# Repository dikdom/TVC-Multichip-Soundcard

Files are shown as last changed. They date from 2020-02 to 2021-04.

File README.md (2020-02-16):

# TVC-Multichip-Soundcard
## English description
  
This is soundcard developed specifically for the Videoton TV Computer. You can find sources of the firmware and music player in the 
**source/** directory and you can also find the plans of the PCB (with schematic) and gerber files in case you would like to do one in 
the **hardware/** directory.

The card is capable of handling three different kind of sound chips: SN76489, SAA1099 and YM3812

These chips' specifications can be found in the **doc/** directory. There is a small overview about the card (Hungarian) if you would like 
to code it.

## Magyar leírás

Ez a hangkártya a Videoton TV Computer számítógéphez készült. Minden megtalálható hozzá: a firmware és a zenelejátszó források a **source/** 
könyvtár alatt, a kapcsolási rajz és nyákterv (gerber file-ok) pedig a **hardware/** könyvtárban van.

A kártya a következő típusú chipeket tudja fogadni (akár egyszerre): SN76489, SAA1099 and YM3812

Van egy kis leírás a kártyáról magyarul itt: **doc/**, illetve ezen chipek specifikációi is megtalálhatóak ugyanitt.

# License
Creative Commons License

This work is licensed under Creative Commons Attribution-NonCommercial-ShareAlike 4.0 International License.

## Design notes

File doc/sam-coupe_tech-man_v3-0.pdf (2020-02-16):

I

MILES GORDON TECHNOLOGY plc

SAM COUPE TECHNICAL MANUAL

version 3.0

(C) 1990

The purpose of this manual is to introduce hardware and software developers to the internal and external workings of the SAM Coupe computer. To this end it is a technical document assuming a certain amount of technical knowledge.

It is MGT's policy that the SAM Coupe and associated MGT products should be fully documented to help third party software and hardware developers take full advantage of all the Coupe's advanced features. If you are developing a product for the Coupe and require further clarification or explanation MGT technical staff will be pleased to assist.

All production machines contain ROM 1.0. This manual details information for ROM 1.0 and ROM 1.2. In the period April/May 1990 all Coupe owners will be issued with an enhanced ROM, issue 2.0, free of charge. The ROM 1.2 referred to in this manual is a pre-production version of ROM 2.0.

written by
Bruce Gordon a Andy Wright

With additional information by Gary Thomas & Adrian Parker

Supplementary information on the use of the SAA1099 sound chip by Andy Graharn

With special Thanks to
Bob Brenchley, Simon Goodwin, W.Ettrick Thomson, and Nev Young

While every effort has been made to ensure that the contents of this manual are correct in every particular, it must be appreciated that MGT cannot guarantee that it is definitive since we have a policy of continual product enhancement.

Published by Miles Gordon Technology plc
Century Park | Valley Way Swansea | SA6 8QP
Tel: 0792 791100 Fax: 0792 791175

II

TECHNICAL SUPPORT FOR PROFESSIONAL DEVELOPERS

More and more hardware and software developers are working on SAM Coupe products.

HGT is keen to support the efforts of developers. To this end we have created the MGT SAM Coupe Developers Group. For a fee of £50.00 we offer members of the Developers Group the following benefits:

Unlimited telephone support from our Software Engineers.

Unlimited telephone support from our Hardware Engineers.

Free and first-off-the-press updates to the Technical Manual.

Free copies of supplementary information provided by developers, (where permission to distribute such information has been given).

Hardware | port address allocation for hardware | developers. | This will
avoid the possibility of two devices Using the same port address(es).
SAM | Compatible: if a product, hardware or software, | works | with the
Coupe we can issue 'SAM Compatible' stickers for the | product case or
packaging.

Developers Group registration number to ensure priority service.

If you require further information, or wish to join the Developers Group, please either write to, or phone, our Technical Department whose staff will be pleased to help you.

III

CONTENTS

THE SAM COUPE HARDWARE

GENERAL SPECIFICATIONS | 1
INTERFACES | 3
MIDI IN | 3
MIDI OUT | 3
BREAK (NMI) BUTTON | 4
JOYSTICK | 4
MOUSE PORT | 4
RESET BUTTON | 5
CASSETTE JACK | 5
LIGHT PEN & AUDIO PORT | 5
POWER INPUT | 5
EUROCONNECTOR (EXPANSION CONNECTOR) | 6
SCART SOCKET | 10
UHF OUTPUT | 10
SLIMLINE SLOT-TN DISK DRIVES | 11
DISK DRIVE INTERFACE | 12
MEMORY | 13
INTRODUCTION | 13
SCREEN MODES | 15
INTRODUCTION | 15
MODE 1 | 15
MODE 2 | 15
MODE 3 | 15
MODE 4 | 15
LOCATING THE CURRENT SCREEN | 16
KEYBOARD | 16
INPUT/OUTPUT PORTS | 17
WRITE (OUTPUT) PORTS | 17
READ (INPUT) PORTS | 21
PHILIPS SAA1099 SOUND CHIP | 23
INTRODUCTION | 23
NOISE & SOUND | 23
PITCH | 24
MUSIC | 24
THE CHROMATIC SCALE | 24
OCTAVE REGISTERS | 25
AMPLITUDE REGISTERS | 25
NOISE GENERATORS | 26
ENVELOPE REGISTERS | 26

IV

CONTENTS

THE SAM COUPE SOFTWARE
MEMORY | 27
SAM COUPE MEMORY MAP | 27
SCREEN MEMORY LOCATION | 29
THE STACK | 29
ROM | 29
USE OF ROM SUBROUTINES | 29
USING SCREEN MODES 3 & 4 | 30
PALETTE SWITCHING | 30
THE PAGING SYSTEM | 31
ROM RESOURCES (JUMP TABLE) | 32
CHARACTER SET | 43
VECTORS | 43
FLOATING POINT CALCULATOR COMMAND CODES | 49
TAPE SYSTEM | 53
FILE HEADER FORMAT | 53
SAM BASIC | 55
BASIC/MACHINE CODE INTERFACE | 56
MAJOR POINTERS TO BASICS MEMORY AREA | 57
PACE ALLOCATION TABLE | 58
KEYBOARD | 59
STREAMS & CHANNELS | 60
SOUND | 62
GRAPHICS SCALING SYSTEM | 64
KEYWORD CODES | 65
SYSTEM VARIABLES | 67
VARIABLE FORMATS | 76
FORMAT OF A BASIC PROGRAM | 77

V

CONTENTS

THE SAM COUPE DISK OPERATING SYSTEM

INTRODUCTION | 78
DISK DRIVES | 78
DISK FORMAT | 78
DISK FILE HEADER | 78
FILE TYPES | 79
MODULO LENGTH & NUMBER OF PAGES | 79
OFFSET START & STARTING PAGE NUMBER | 79
SAHDOS DIRECTORY | 80
SECTOR ADDRESS MAP | 81
BIT ADDRESS MAP | 81
SAMDOS INTERFACING | 82
USER INFORMATION FILE AREA (UIFA) | 82
SAMDOS HOOK CODES | 83
LOCATING SAMDOS | 85
SAMDOS ERROR CODES | 86

APPENDIX A: PHILIPS SAA1099 SOUND CHIP

APPENDIX B: VLSI VL-1772-02 FLOPPY DISK CONTROLLER CHIP

APPENDIX C: DIAGRAMS

INDEX

STOP PRESS

Sam Coupe Technical Manual version 3.0 | 1

THE SAM COUPE HARDWARE

The SAM Coupe is a modern micro-computer using a Z80B microprocessor running at 6MHz. It has 256K RAM as standard, with an expansion socket to allow the memory to be doubled to 512K with a small expansion board.

The machine's main controller is a VLSI VGT-200 gate array (ASIC), customised to carry out the main tasks of processor/video contention, paging and management of all memory, video memory mapping, colour palette table allocation, and all input/output port control. There are four modes of video operation with a hardware capacity to show 16 colours from a palette of 128 on each screen line.

The sound for the machine is generated by a Philips SAA1099, with a capability in stereo of six channels over eight octaves with 256 tones per octave, two white noise generators, six amplitude controllers and two envelope wave shapers.

GENERAL SPECIFICATIONS
CPU | Z80B microprocessor running at 6MHz
Special | Customised VLSI 10,000-gate ASIC chip
ROM | 32K x 8 ROM, 150nS, containing SAM BASIC, disk
bootstrap, BIOS
RAM | 256K upgradeable to 512K (256K x 4 100ns DRAM)
Sound | Philips SM 1099 Synthesizer: 6 channels, 8 octaves,
stereo with amplitude and envelope control, plus choice of wave form.

Graphics Motorola MC 1377P video Chip. ASIC serves as graphics processor, offering four modes:

Mode 1 | 32 x 24 character cells per screen, each cell
capable of 2 colours; 16 colours selectable | from
12e; Spectrum-attribute compatible.
Mode 2 | As mode 1, but with 32 x 192 cells, each cell
capable of 2 colours: 16 colours selectable | from
128.
Mode 3 | 80 column text display - 512 x 192 pixel screen;
each pixel selectable for colour; 4 colours | per
line selectable from 128.
Mode 4 | 256 x 192 pixel graphics screen; each | pixel
selectable for colour; 16 colours selectable | per
| line from 128.

Sam Coupe Technical Manual version 3.0 | 2

In all modes, colours may be redefined at line interrupt, allowing all 128 colours to be displayed on-screen.

UHF (TV channel 36), through power supply unit. Colour composite video, digital and linear RGB, all through SCART.

Atari-standard joystick (dual capability with splitter cable).

Mouse - Coupe standard.

Light-pen, Light-gun - Coupe standard. Audio output socket.

Domestic cassette recorder.

MIDI In, MIDI Out (MIDI Through, via software switch). Network -screened microphone cable with 7 pin DIN connectors.

RS232 and parallel printer via external }4GT interface connected at expansion port.

64-pin Euroconnector for further peripherals.

Disk Drives 1 or 2 removable and internally mounted 3.5” ultra-slim Citizen drives, 1 Mb unformatted, 780K formatted.

Keyboard 72 full travel keys, membrane type, including 10 function keys (software defined).

Power Consumption 11.2 Watts.

Shock | - Operating 3 G
- Non-operating 60 0
Vibration | - Operating | 5 - 500Hz / 0.5 G
| - Non-operating | 5 - 500Hz / 2 G
Environmental: Ambient Temperature | Operating 5 - 45 C
| | Storage -20 - 50 C
Relative Humidity | | Operating 20 - 80%
Wet Bulb Maximum 29,4 C, No Condensation
Reliability: | MTBF: 10,000 POH; MTTR: 30 Mins;
| Component Life: >5 years
Weight | 2.26Kg (4.97 lb)
Power Supply | Primary Input voltage | 240v AC 50Hz
Secondary Output voltage 5v DC 2A Maximum Rating
| | 12v DC 2OOmA Maximum Rating

Sam Coupe Technical Manual version 3.0 | 3

INTERFACES -

All connections to the Coupe except the removable internal disk drives, and the RAM expansion socket are made via the rear panel. please refer to the Input/Output Port map where reference is made to bits and registers.

- MIDI IN -

Standard 7 pin DIN type connector. This serial input, working at
31.25 Kbaud is fed via an opto-isolator to a serial/parallel converter, which interrupts the CPU when a data byte has been assembled in the MIDI-IN register (253 dec). This INPUT can also be read by bit 7 of the Video Memory Page Register VMPR (252 dec). This connector is also used by the network.
PIN | SIGNAL
1 | NET | - LOOP
2 | N.C.
3 | NET | + LOOP
4 | MIDI + IN
5 | MIDI - IN
6 | NET | - LOOP
7 | NET | + LOOP
- MIDI OUT -

Standard 7 pin DIN type connector. By writing a data byte to the MIDI-OUT register (253 dec), the MIDI outputs a 7.5 mA current at 31.25 Kbaud. when transmitting, bit 1 of the PEN register (TXFMST of register 248 dec), is set. This OUTPUT can also be driven by bit 7 of the VMPR (252 dec). An internal through connection is made from MIDI IN to OUT by setting bit 6 THROM - through MIDI) of the BORDER register (254 dec). This connector is also used by the network, An interrupt is given on completion of the transmission of MIDI data.

PIN | SIGNAL
1 | NET | - LOOP
2 | GND
3 | NET | + LOOP
4 | NIDI + OUT
5 | MIDI - OUT
6 | NET | - LOOP
7 | NET | + LOOP

Sam Coupe Technical Manual version 3.0 | 4
- BREAK (NMI) BUTTON -

When pressed, this button forces the CPU to address (0066H) where it is vectored to any assignable address in the memory map. A versatile function for programmers to assign a vector, to enable its use as an ESC, BREAK or CRASH key. When the Disk Operating System Spectrum Emulator is loaded this button is used to activate the snapshot facility.

- JOYSTICK -

Standard 9 pin 'D' type plug. The joystick interface has standard ATARI connections except that it has an extra strobe line for a second joystick together with a line carrying 5 volts. MGT will allow for dual joystick control with the second joystick having a special plug-socket connector. The joystick is read by the Key-board port (254 dec) and overlays numeric keys 1 to 5 for second joystick and 6 to 0 for the first joystick.

PIN | SIGNAL
1 | UP
2 | DOWN
3 | LEFT
4 | RIGHT
5 | 0 VOLTS
6 | FIRE
7 | +5 VOLTS
8 | STROBEL 1
9 | STROBEL 2
- MOUSE PORT -

Proprietary 5 pin DIN type connector. The MGT mouse interrupts the CPU to request a read of its X and Y signal lines. The software driver is integral to the ROM and overlays the cursor control keys. The mouse input can be read by Keyboard port (254 dec) with address lines A8 to A15 set high. (RDMSEL}.

PIN | SIGNAL
1 | DOWN
2 | UP
3 | CTRL
4 | LEFT
5 | RIGHT
6 | MSE INT.
7 | RDMSEL
8 | +5 VOLTS
SCREEN | GROUND.

Sam Coupe Technical Manual version 3.0 | 5
- RESET BUTTON -

When pressed this button causes the CPU to clear and restart at memory location (0000H). It also resets the following:

1. Floppy Disk Controller (Disk 1 and 2)
2. Memory page registers
3. MIDI receive and transmit registers
4. Border register

It does not reset the colour look up table, the sound chip registers or the LINE INTerupt register (249 dec) value. The ROM normally initialises LINE INT as part of its initialisation.

- CASSETTE JACK -

Standard 3.5mm mono jack socket. This is a bi-directional line. when outputting it should be connected to the MIC socket of a standard cassette tape recorder; when inputting it should be connected to the EAR socket of the recorder. It makes no difference to the Coupe if EAR and MIC are connected together, but only some tape recorders allow this, because of positive feedback.

- LIGHT PEN & AUDIO PORT -

Standard 5-pin, 180 degree, DIN type connector. This connector has a dual function of light-pen/gun input as well as stereo sound output capable at driving a HI-FI system on the AUX input.

PIN | SIGNAL
1 | +5 VOLTS
2 | AUDIO LEFT OUTPUT
3 | 0 VOLTS
4 | SPEN INPUT
5 | AUDIO RIGHT OUTPUT
- POWER INPUT -

Regulated DC input of 12 Volts at 200 milliamps and 5 Volts at 2 Amps. A fully loaded machine will have a power consumption of approximately 15 watts.

PIN | SIGNAL
1 | +5 VOLTS
2 | o VOLTS (SIGNAL GROUND)
3 | o VOLTS (DIGITAL GROUND)
4 | COMPOSITE VIDEO
5 | +12 VOLTS
6 | SOUND OUTPUT (MONO)

Sam Coupe Technical Manual version 3.0 | 6
- EUROCONNECTOR (EXPANSION CONNECTOR) -

The Coupe's Euroconnector is a standard 64 pin type with rows A-C fitted. It has all the typical hardware signals found on other computer expansion ports. In addition, we include many extra hardware signals on the connector. This allows the hardware designer a hitherto unknown flexibility and control of a microcomputer from an external device.

SIGNALS

(NB row A is at the bottom of the Euroconnector, row C at the top).

PIN | SIGNAL | PIN | SIGNAL
lA | DBDIR | 1C | IORQL
2A | RDL | 2C | MREQL
3A | WRL | 3C | HALTL
4A | BUSAKL | 4C | NMIL
5A | WAITL | 5C | INTL
6A | BUSREOL | 6C | CD1
7A | RESETL | 7C | CD0
8A | CM1L | 8C | CD7
9A | REFRESHL | 9C | CD2
1OA | 0 VOLTS | 10C | +5 VOLTS
1lA | AO | l1C | CD6
1ZA | Al | 12C | CD5
13A | A2 | 13C | CD3
14A | A3 | 14C | CD4
15A | A4 | 15C | CPU CLK
16A | A5 | 16C | Al5
17A | A6 | 17C | A14
l8A | A7 | 18C | Al3
19A | A8 | 19C | A12
20A | A9 | 20C | All
21A | Al0 | 21C | DISK 2L
22A | MSEINTL | 22C | ROMCSL
23A | XMEML | 23C | EARMIC
24A | 8 MHz | 24C | DISK 1L
25A | RED 1 | 25C | PRINTL
26A | GREEN 1 | 26C | BLUE 1
27A | C SYNC | 27C | ROMCSRL
28A | SPEN | 28C | AUDIO RIGHT OUTPUT
29A | BLUE 0 | 29C | AUDIO LEFT OUTPUT
30A | RED 0 | 30C | COMP VIDEO
31A | BRIGHT | 31C | GREEN 0
32A | +5 VOLTS | 32C | 0 VOLTS

when looking at the back of the Coupe's expansion connector, the pins are numbered as follows:

Euroconnector
Pin 1C | Pin 32C
Pin lA | Pin 32A

Sam Coupe Technical Manual version 3.0 | 7

For details of Z80B timing signals refer to any standard Z80 text. Please note that we will be releasing the SAM Coupe Multi Expansion (SME) in the near future. (This product has been referred to as the Card Cage in some of our literature). Some of the signals described here must be included in any designs to ensure their correct operation when used with the SME.

DBDIR (lA) | This signal is not used by the computer but must be
driven by all external devices to allow their use with the SME. The SME has buffers present to prevent undue
loading of the machine. | However, | it | is the
responsibility of the hardware designer to ensure that the data bus transceiver has its direction bit set according to the operation (read or write) being performed. The operation should be as follows:
1. Processor sends out an address.
2. External device decodes address.
3. External device drives the DBDIR line, from an open collector output, LOW for a processor READ.
It is configured as a WIRED-OR internally to the computer.
4. Normal handshaking is continued with the Z80B for data transfer.
RDL (2A} | Read signal from the processor.
WRL (3A} | Write signal from the processor.
BUSAKL (4A) | Bus acknowledge signal from the processor.
WAITL (5A) | Wait signal to processor.
BUSREQL (6A) | Bus request signal to external device.
RESETL (7A) | This is a system reset generated by a 10 Kilohm
resistor charging a 47 microfarad capacitor. This gives
a | pulse | of | approximately | 330ms | duration. | It | is
suggested that if a sharp reset edge is required, this signal is passed through a schmitt inverter.
CM1L (6A) | Op-code fetch signal from the processor
REFRESHL (9A) | Refresh signal from the processor.
0 V (lOA) | Zero Volt: not to be used as a supply rail.
A0 (11A) | Address lines A0 to Al0 from the processor are on pins
11A to 21A.

MSEINTL (22A) Mouse interrupt signal also present on the mouse port. The signal is pulled low by an external device to notify the processor that the mouse co-ordinates have changed.

Sam Coupe Technical Manual version 3.0 | 8
XMEML (23A) | External memory signal which will be driven low when
the processor requires to switch out the internal memory and 8ccess the external memory. Please note that only memory above address 8000H in each block of 64K will be switched out. It is the responsibility of the peripheral designer to ensure that the DIEM signal is included in the address decoding circuitry of the design, to avoid contention between the internal RAM and the external device.
8MHZ (24A) | 8 MegaHertz clock signal.
RED1 (25A) | Each | colour | is | generated | by | three | colour driver
signals, the intensity of which is determined by three bits each. RED1 is the MSB (Nest significant Bit) of the red colour signal at the current pixel position.

GREEN1 (26A) GREEN1 is the MSB of the green colour signal (see pin 25A for a full description).

CSYNC (27A) Composite Sync for video circuitry as on the SCART connector.

SPEN (28A) | Light pen signal (active high) which is normally low.
When the light pen is touched to the screen and the raster passes the point of the pen, a positive going edge is received on this signal from the light pen socket. This causes the two registers LPEN and HPEN to contain the current x and y co-ordinates of the light pen, respectively.

BLUE0 (29A) BLUE0 is the second bit of the blue colour signal (see pin 25A for a full description).

RED0 (30A) | REDO is the second bit of the red colour signal (see
pin 25A for a full description).

BRIGHT (31A) BRIGHT is the LSB (Least significant Bit) of all colour signals (see pin 25A for a full description).

+5V (32A) | +5 volt supply rail, up to 250 mA available.
IORQL (1C) | Input/output Request becomes active when the address
bus contains a current port address from the processor.
MREQL (2C) | Memory Request becomes active when the address bus
contains a current memory address front the processor.

Sam Coupe Technical Manual version 3.0 | 9
HALTL (3C) | Halt indicates from the processor that it has executed a HALT instruction and is waiting for an interrupt.
NMIL (4C) | Non Maskable Interrupt causes the processor to execute a jump, from which it may be vectored anywhere by the user. It is used as a BREAK button by BASIC, and a SNAPSHOT button by the DOS. It is pulled up by a 10 Kilohm resistor internally, and should therefore be driven low by an open collector circuit.
INTL (5C} | Maskable Interrupt is used to interrupt the processor from its current task if the interrupts are currently enabled.
CD1 (6C) | Data lines Dl,D0,D7 and D2 are on pins 6C to 9C.
+5V (l0C) | +5 Volt reference only.
CD6 (l1C) | Data lines D6,D5,D3 and D4 are on pins l1C to 14C.
CPUCLK (15C) | The 6 MegaHertz clock signal to the processor.
A15 (16C) | Address lines Al5 to All are on pins 16C to 20C.
DISK2L (21C) | DISK2 is the decoded base address for the eight ports of drive 2.
ROMCSL (22C) | ROM chip select is pulled high to disable the internal ROM (Used in conjunction with ROMCSR on pin 27C)4 It indicates when the ROM is being accessed.
EARMIC (23C) | EARMIC is connected to the logic level side of the cassette port circuitry.
DISKiL (24C) | DISK1 is the decoded base address for the eight ports of drive 1.
PRINTL (25C) | PRINT is the decoded address for either of the two possible printer addresses (246 and 248).
BLUEl (26C) | BLUE1 is the MSB of the blue colour signal (see pin 25A for a full description).
ROMCSRL (27C) | ROMCSR is connected to the ROMCS (22C) pin via a 1 Kilohm resistor. If ROMCS is pulled high by an external circuit, then ROMCSR could be used as a chip select for an external ROM which would then take the place on the internal one.

Sam Coupe Technical Manual version 3.0 | 10
AUDIORIGHT(28C | The right audio signal, as on the light pen socket, is brought out here.(5ornV pp as per auxiliary standard input) It must be amplified before being applied to a speaker.
AUDIOLEFT(29C) | The left audio signal is present on this pin. The same precautions and signal levels as for AUDIORIGHT apply.
CVID (30C) | Composite Video, as sent to the modulator and SCART socket is present on this pin.
GREENO (31C} | GREENO is the second bit of the green colour signal (see pin 25A for a full description).
0 V (32C) | Zero Volt supply rail.
- SCART SOCKET -

SCART socket to handle all video and sound outputs. Please note that not all connections are standard.

PIN SIGNAL | PIN | SIGNAL
1 | AUDIO OUT RH | 2 | SPEN
3 | AUDIO OUT LH | 4 | AUDIO EARTH
5 | BLUE EARTH | 6 | BLUE | TTL OUT
7 | BLUE LIN. OUT | 8 | RED | TTL OUT
9 | GREEN EARTH | 10 | GREEN TTL OUT
11 | GREEN LIN. OUT | 12 | +5V POWER IN
13 | RED | EARTH | 14 | CSYNC EARTH
15 | RED | LIN. OUT | 16 | CSYNC
17 | C.VID EARTH | 18 | +12V POWER IN
19 | C.VID OUT | 20 | BRIGHT TTL OUT
21 | GND.
- UHF OUTPUT -

UHF television standard video and mono sound are output on channel 36; the UHF output is in the power supply box.

Sam Coupe Technical Manual version 3.0 | 11
- SLIMLINE SLOT-IN DISK DRIVES -

The disk drives used in the SAM Coupe are Citizen Slim Line OSDC type 3.5', 1 megabyte (formatted 780 kilobytes).

The Coupe can control up to two disk drives. Connections to the two drives are made via two 32-pin Euroconnectors, with rows A and B connected. Drive 1 is on the left of the machine and drive 2 on the right. A list of signals available at these sockets are shown below.

PIN | SIGNAL | PIN | SIGNAL
lA | 0 VOLTS | 1B | WR
2A | 0 VOLTS | 2B | AO
3A | 0 VOLTS | 3B | Al
4A | 0 VOLTS | 4B | D0
5A | 0 VOLTS | 5B | Dl
6A | 0 VOLTS | 6B | D2
7A | 0 VOLTS | 7B | D3
8A | 0 VOLTS | 8B | D4
9A | 0 VOLTS | 9B | D5
10A | 0 VOLTS | 10B | D6
11A | 5 VOLTS | l1B | D7
12A | 5 VOLTS | 12B | 8 MHz
13A | 5 VOLTS | 13B | RST
14A | 5 VOLTS | 14B | No connection
15A | 5 VOLTS | 15B | A2
166A 5 VOLTS | 16B | DISK 1 OR DISK 2

Sam Coupe Technical Manual version 3.0 | 12
- DISK DRIVE INTERFACE -

The SAM Coupe can be connected to one or two disk drives. These would normally be internal SAM disk drives. However, we have made provision for people to use an external disk drive, (Shugart 400 type 5.25" or 3.5"), if they add the SAM External Drive Interface (SDI). Both the internal drives and the SDI use the VL-1772-02 disk controller chip manufactured by VLSI.

NB All values are given in Decimal.

The SAM Coupe controls each disk drive via 8 I/O mapped ports, as listed below for both drives:

Disk 1 | 224 to 231 inclusive.
Disk 2 | 240 to 247 inclusive.

In each case, the address can be given by:

Disk1base (224) + offset (0 to 7)
Disk2base (240) + offset (0 to 7)

Both sets of offsets perform the same functions on their respective sides of the disk. The first four offsets (0-3) refer to the first side of the disk, and the second four offsets, (4-7) refer to the second side of the disk. Offsets 4-7 can be ignored for single sided disk drives.

The offset determines which register of the 1772 will be accessed as shown below:

OFFSET | READ | WRITE
0 | Status(disk side 1) | Command (disk side 1)
1 | Track | 1 | Track | 1
2 | Sector | 1 | Sector | 1
3 | Data | 1 | Data | 1
4 | status(disk side 2) | Command (disk side 2)
5 | Track | 2 | Track | 2
6 | Sector | 2 | Sector | 2
7 | Data | 2 | Data | 2

For example, to read the current contents of the data register on side 2 of Disk 1:
IN A,(231)
where 231 = Disk1base (224) + offset (7)

For complete information on controlling the 1772 chip refer to the data sheets contained in Appendix H.

Sam Coupe Technical Manual version 3.0 | 13

MEMORY

- INTRODUCTION -

The Coupe can take 512 Kbytes of RAM on board (with extra memory able to be added via the expansion connector using signal XMEML). The basic machine has 256Kb fitted, with an internal expansion connector for an additional 256Kb. The memory used is Dynamic Random Access Memory 256K x 4 bits - 100ns access time, 20 pin dual in-line plastic package.

Because the Z80B CPU (central Processing Unit) is limited to a 64K addressing range, one of the functions of the ASIC (Application Specific Integrated Circuit) in the Coupe is to manage the addressing of this memory by splitting it into 32 pages of 16K.

Sam Coupe Technical Manual version 3.0 | 14

The ASIC controls the paging via two 8-bit read/write registers.

LMPR (Low Memory Page Register)...I/O address 250dec
HMPR (High Memory Page Register}...I/O address 25ldec

The lower 5 bits of each register represent pages 0 to 31. (of course on the basic machine with 256K of memory fitted, the paging is from 0 to 15).

To illustrate the paging system used by the Coupe, it's best to envisage the 64K addressing range of the Z80 as 2 blocks 2 of sections of 16K, represented by the letters A.B and C.D:

64K ADDRESS RANGE

0000 | 4000 | 8000 | C000 | FFFF
SECTION | SECTION | SECTION | SECTION
A | B | C | D
| BLOCK A.B | | BLOCK C.D

LMPR manages the block A.B, and the HMPR manages the block C.D

If we write 00H to the LMPR then page 0 of the memory is allocated to section A of the CPU address range. Section B is always automatically allocated one page above section A, in this case to page 1.

If we write 02H to the HMPR then page 2 of the memory is allocated to section C of the CPU address range. Section D is always automatically allocated one page above section C, in this case to page 3.

In our example the CPU address map would look like this:

64K ADDRESS RANGE

0000 | 4000 | 8000 | C000 | FFFF
PAGE 0 | PAGE 1 | PAGE 2 | PAGE 3
A | B | C | D
| BLOCK A.B | | BLOCK C.D

Sam Coupe Technical Manual version 3.0 | 15

SCREEN MODES

- INTRODUCTION -

There are four screen modes used in the Coupe, each using varying amounts of memory and each having different attributes for use by the programmer.

The hardware pointers which display the contents of the memory are controlled by the VMPR, Video Memory Page Register (252 dec).

By using the lower 5 bits of this register we can access up to 32
pages of video screen memory. It must be noted that modes 3 and 4
use 24 kilo-bytes, which go over the page boundary of 16 kilobybtes. Where this happens, the video addressing hardware
wraps into the next page within the same block. For example:

By entering page 12 to the VMPR, video wraps to page 13

The same applies to any page and the principal of even to odd always applies.

- MODE 1 -

32 cells x 24 lines in 2 colours from 16 out of a palette of 128 colours, giving 768 character cells (8 x 8) using 6 kilobytes of bit-mapped memory and 0.75 kilo-bytes of attribute memory. This mode emulates Spectrum memory mapping.

- MODE 2 -

32 cells x 192 lines in 2 colours from 16 out of a palette of 128 colours, giving 6144 character cells (8 x 1) using 6 kilobytes of bit-mapped memory and 6 kilobytes of attribute memory. This mode has contiguous memory addressing in two blocks.

- MODE 3 -

512 pixels x 192 lines in 4 colours out of a palette of 128 colours, giving 98304 dots using 24 kilo-bytes of memory. This mode, when used with a character set 6 pixels wide, will give 85 characters per line.

- MODE 4 -

256 pixels x 192 lines in 16 colours out of a palette of 128 colours, giving 49252 dots using 24 kilo-bytes of memory. This mode is ideal for graphic display, and when used in conjunction with LINE INTerrupt register can display the full 128 colours on screen.

Sam Coupe Technical Manual version 3.0 | 16
- LOCATING THE CURRENT SCREEN -

The SAM Coupe provides a port called Video Memory Page Register (address 252). To locate the base address of the currently displayed screen use the following BASIC program:

10 LET A=IN 252 BAND 31 | REM Input the current page
20 LET BASE=(A+1) * 16384 | REM BASE now equals start
REM of screen area.

KEYBOARD

The Coupe has a full-travel 72 key keyboard. It is addressed as
a 9 x 8 matrix, using two ports, KEYBOARD (254 dec) and STATUS
(249 dec).

The 8 input lines are made up by the KEYBOARD port inputting the lower 5 bits represented by K1, K2, K3, K4 and K5, while the STATUS port inputs the upper 3 bits represented by K6, K7 and K8.

The 9 output scan lines are made up by the CPU address lines AD8, AD9, ADl0, ADl1, AD12, AD13, AD14, AD15 and the ASIC line RDMSEL.

An example of a typical keyboard scan:

LD | HL,SCAN | ;set HL with buffer start
LD | B,lllllll0bin | ;set upper address lines
LOOP LD | C,HIKEY | ;port address K6 - K8
IN | A,(C)
AND | lll00000bin | ;strip unwanted bits
LD | (HL),A | ;hold it
LD | C, LOKEY | ;port address K1 - K5
IN | A, (C)
AND | 000lllllbin | ;strip unwanted bits
OR | (HL) | ;make K1 - K8
LD | (HL),A | ;save it
INC | HL | ;next location in buffer
SCF | | ;set carry flag for
RLC | B | ;rotate next address line
JR | C,LOOP | ;jump if not done
IN | A,(C) | ;input RDMSEL line
AND | 00011111bin | ;strip unwanted bits
LD | (HL),A | ;save it
RET | | ;return to analyse scan

Sam Coupe Technical Manual version 3.0 | 17

INPUT/OUTPUT PORTS

The SAM Coupe can address 64k of ports. Addresses 224 (EOH) to 255(FFH) are allocated to the Coupe itself. Refer to the diagram provided for an overview of these ports and their contents.

- WRITE (OUTPUT) PORTS -

SOUND ports (address port 511 dec) and (data port 255 dec)

The sound chip, a Philips SAA1099, is controlled through these two port addresses. The sound chip is controlled in BASIC through using the SOUND a,d command. See the attached Philips application notes and the SAA1099 supplements included elsewhere for further information.

VMPR - Video Memory Page Register (252 dec)

This read/ write register mainly controls the page addressing for the screen display memory.

Bit 0 R/W | BCD 1 | | of video page control.
Bit 1 R/W | RCD 2 | | of video page control.
Bit 2 R/W | BCD 4 | | of video page control.
Bit 3 R/W | BCD 8 | | of video page control.
Bit 4 R/W | BCD 16 | of video bank control, used to switch
| | | between the banks of 256 kilobytes.
Bit 5 R/W | MDEO | | first bit of screen mode control.
Bit 6 R/W | MDE1 | | second bit of screen mode control.
Bit 7 -/W | TXMIDI | output bit to directly drive the MIDI
| | | OUT channel.
Bit 7 R/- | RXMIDI | input bit from MIDI IN channel.

HMPR - High Memory Page Register (251 dec)

This read/write register is used mainly for the control of paging memory in the CPU's addressing range.

Bit 0 R/W | BCD | 1 | of high memory page control.
Bit 1 R/W | BCD | 2 | of high memory page control.
Bit 2 R/W | BCD | 3 | of high memory page control.
Bit 3 R/W | BCD | 4 | of high memory page control.
Bit 4 R/W | BCD | 16 | of high memory page control.
Bit 5 R/W | MD3S0 | | BCD 4 of the colour look-up address
| | | available only in mode 3.
Bit 6 R/W | MD3S1 | | BCD 8 of the colour look-up address
| | | available only in mode 3.
Bit 7 R/W | MCNTRL | If this bit is set when the CPU
| | | addresses high memory, then the
(See section entitled | external signal XMEM goes low and
CLUT IN MODE 4 & MODE 3 | the Coupe looks on its expansion
in the text ahead) | connector for memory sections C and
| | | D (addresses 32768 to 65536).

Sam Coupe Technical Manual version 3.0 | 18

LMPR - Low Memory Page Register (250 dec)

This read/write register is used mainly for the control of paging low memory in the CPU's addressing range.

Bit 0 | R/W | BCD 1 | of low memory page control.
Bit 1 | R/W | BCD 2 | of low memory page control.
Bit 2 | R/W | BCD 4 | of low memory page control.
Bit 3 | R/W | BCD 8 | of low memory page control.
Bit 4 | R/W | BCD 16 | of low memory bank control.
Bit 5 | R/W | RAM0 | when bit set high, RAM replaces the
| | | first half of the ROM (ie ROM0) in
| | | section A of the CPU address map.
Bit 6 | R/W | ROM1 | when bit set high, the second half
| | | of the ROM (ie ROM1) replaces the
| | | RAM in section D of the CPU address
| | | map
Bit 7 | R/W | WPRAM | Write Protection of the RAM in
| | | section A of the CPU address map is
| | | enabled when this bit is set high.

MIDI OUT port (253 dec)

By writing a data byte to this port, the hardware automatically transmits through the MIDI out channel at 31.25 kbaud, the standard for MIDI protocol. Bit 4 of the STATUS register (249 dec) is set high when this register is full.

BORDER port (254 dec)

This output port mainly controls the border colour of the screen by supplying a 4-bit address to the Colour Look Up Table (CLUT), to enable a colour to be displayed during border time.

Bit 0 | BCD 1 of CLUT address for border colour.
Bit 1 | BCD 2 of CLUT address for border colour.
Bit 2 | BCD 4 of CLUT address for border colour.
Bit 3 | MIC | output control bit, normally set high.
Bit 4 | BEEP output control bit, normally set low.
Bit 5 | BCD 8 of CLUT address for border colour.
Bit 6 | THROM bit set high to allow through MIDI operation
Bit 7 | SOFF bit set high to disable screen display, only
active in screen modes 3 and 4, also re moves memory contention during off period.

LINE INTerrupt register (249 Dec)

This write-only register will cause an interrupt to the CPU at the end of the scan-line before the one matching its contents, (ie at the start of the right hand border). This works even for the first scan line. Line numbers are from 0 to 191. This function is always enabled, so to inhibit its operation a false line number from 192 to 255 can be entered. A useful function of this register can be to switch video modes or change colour lookup table values.

Sam Coupe Technical Manual version 3.0 | 19

CLUT - Colour Look Up Table (base port 248 dec)

There are 16 write only 7 bit registers in the CLUT:
colour | 0 | addresses register 0 | on port | 248
colour | 1 | addresses register 1 | on port | 504
colour | 2 | addresses register 2 | on port | 760
colour | 3 | addresses register 3 | on port | 1016
colour | 4 | addresses register 4 | on port | 1272
colour | 5 | addresses register 5 | on port | 1528
colour | 6 | addresses register 6 | on port | 1784
colour | 7 | addresses register 7 | on port | 2040
colour | 8 | addresses register 8 | on port | 2296
colour | 9 | addresses register 9 | on port | 2552
colour | 10 | addresses register A | on port | 2808
colour | 11 | addresses register B | on port | 3064
colour | 12 | addresses register C | on port | 3320
colour | 13 | addresses register D | on port | 3576
colour | 14 | addresses register E | on port | 3832
colour | 15 | addresses register F | on port | 4088

Each register has 7 bits to represent 1 of 128 possible colours.

Bit 0 BLUO | least significant bit of blue.
Bit 1 REDO | least significant bit of red.
Bit 2 GRNO | least significant bit of green.
Bit 3 BRIGHT | half bit intensity on all colours.
Bit 4 BLU1 | most significant bit of blue.
Bit S RED1 | most significant bit of red.
Bit 6 GRN1 | most significant bit of green.

The registers at switch on will be loaded from the ROM with a default set of values corresponding to:

register 0 black ( 0) register 8 black | (0)
register 1 blue | (16) register 9 bright blue | (17)
register 2 red | (32) register A bright red | (34)
register 3 magenta(48) register B bright magenta | (51)
register 4 green (64) register C bright green | (68)
register 5 cyan | (18) register D bright cyan | (85)
register 6 yellow (96) register E bright yellow | (102)
register 7 white (120) register F bright white | (127)

The colour numbers are found by:
FOR c=0 TO 15 : PRINT PEEK (&55D8+c) : NEXT C

A typical routine for loading the CLUT from a memory table:

LD | HL,TABLE | ;load HL with top of table
LD | B,16 | ;load B with size of table
LD | C,248 | ;load C with port address
OTDR | | ;execute a decrement B,
| | ;output to port (C) and
| | ;decrement HL until B=O
RET | ;return to calling routine

Sam Coupe Technical Manual version 3.0 | 20

CLUT IN MODE 4 & MODE 3

MODE 4

In screen mode 4, 4 bits are used to address the CLUT for the colour of a pixel. Within a byte, the most significant nibble refers to the first pixel and the least significant nibble refers to the second pixel.

MODE 3

The situation is similar in screen mode 3, however this time there are only 2 bits per pixel which address the CLUT. Out of an 8-bit data byte, the first two most significant bits are used as the address for the first pixel.

Normally, only 4 of the sixteen possible registers would be available. This is overcome by using an extra two bits from the high memory page register (HMPR-251 dec). Bit 5 of HMPR is used to access BCD 4 of the colour look up address and bit 6 of HMPR is used to access BCD 8 of the colour look-up address.

In this way, we can still access the 16 colours specified in the colour look-up table whilst having high resolution graphics.

Sam Coupe Technical Manual version 3.0 | 21
- READ (INPUT) PORTS -

ATTRIBUTES register (255 dec)

This register enables the programmer to read the attributes of the currently displayed character cell in modes 1 and 2, and the third byte in every four displayed in modes 3 and 4.

KEYBOARD register (254 dec)

This read only register is mainly used for inputting the lower 5 bits of the keyboard matrix. It is also the input for the MOUSE when
the address lines AD8 - AD15 are high.
Bit 0 | K1 | keyboard matrix line 1, Mouse Control.
Bit 1 | K2 | keyboard matrix line 2, Mouse Up.
Bit 2 | K3 | keyboard matrix line 3, Mouse Down/Button 2.
Bit 3 | K4 | keyboard matrix line 4, Mouse Left/Button 1.
Bit 4 | K5 | keyboard matrix line 5, Mouse Right/Button 3.
Bit 5 | SPEN light pen strobe/serial input bit.
Bit 6 | EAR | serial input from EAR of cassette recorder.
Bit 7 | SOFF status bit show if external memory is set.

MIDI IN register (253 dec)

This read-only register generates an interrupt to the CPU when a data byte has been read from the MIDI serial input interface. The data must be read by the CPU before the next interrupt (typically 320 µS).

STATUS register (249 dec)

This read-only register is mainly used for reading interrupt status. Although all five interrupts go to the CPU operating under mode 1 interrupt, there is no way of knowing which one is requesting, therefore a read of this register is necessary. Approximate interrupt times are 20 µs long.

Bit 0 | LINE | int when low, signals the line interrupt
| | register is requesting.
Bit 1 | MOUSE int when low, signals the mouse
| | requests the interrupt.
Bit 2 | MIDIIN int when low, signals the MIDI channel
| | has a data byte.
Bit 3 | FRAME int when low, signals the frame scan
| | has been completed (50 per/second).
Bit 4 | MIDOUT int when low, indicates the NrDr out
| | register has just completed data
| | output.
Bit 5 | K6 | keyboard matrix line 6.
Bit 6 | K7 | keyboard matrix line 7.
Bit 7 | K8 | keyboard matrix line 8.

Sam Coupe Technical Manual version 3.0 | 22

PEN registers (LPEN - 248 dec) (HPEN - 504 dec)

If the light pen is not connected, these read-only registers are continuously updating with the current position of the scan. The LPEN register is connected to the horizontal or X co-ordinate of the scan function and HPEN is connected to the vertical or Y coordinate of the scan function.

The first two bits of the LPEN register are:

Bit 0 - Inputs BCD 1 of the current colour look up table address.
Bit 1 - TXFMST is the status bit for MIDI OUT. When this is high it shows that a byte is being transmitted.

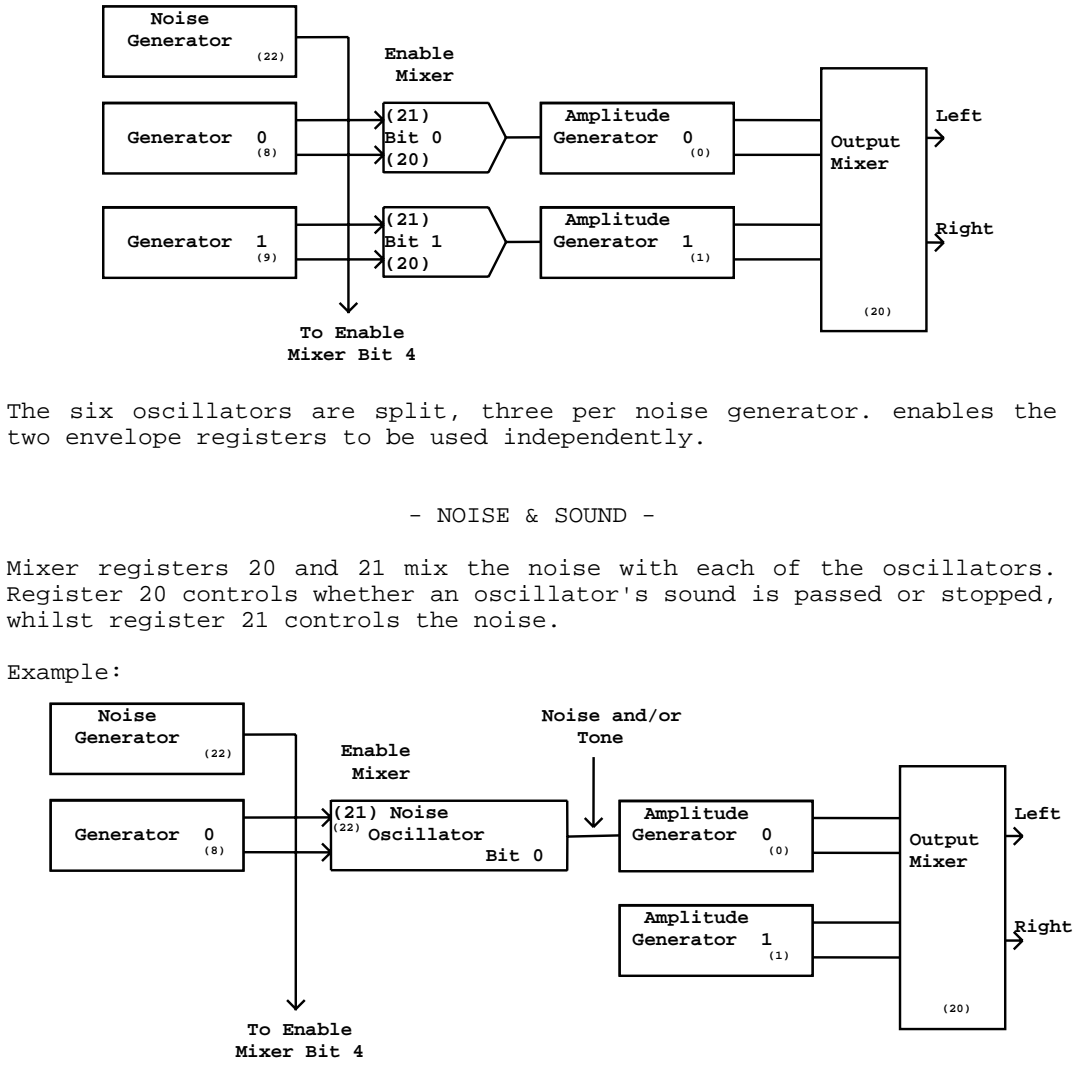
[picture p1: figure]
(21) Bit 0 (20); (21) Noise (22) Oscillator Bit 0; (21) Bit 1 (20); Left; Right; - NOISE & SOUND -; whilst register 21 controls the noise.; Example:; Output Mixer; Generator 0 (8); Generator 1 (9); Noise Generator; Amplitude Generator 0 (0); Amplitude Generator 1 (1); Enable Mixer; To Enable Mixer Bit 4; Noise and/or Tone

Sam Coupe Technical Manual version 3.0 | 23

PHILIPS SAA1099 SOUND CHIP

- INTRODUCTION -

The sound chip has six tone registers or oscillators and two noise generators. These can all be panned individually from left to right across the stereo field using one of the 256 possible positions, {ie. 16 volumes per channel, thus 16 x 16 combinations gives 256 positions). The position in the stereo field, relating to that particular oscillator, is controlled by its amplitude register. The overall sound can be enabled or disabled using output mixer (28). To hear sound, this register should be '1', to kill the sound, it should be 0.

The six oscillators are split, three per noise generator. enables the two envelope registers to be used independently.

Mixer registers 20 and 21 mix the noise with each of the oscillators. Register 20 controls whether an oscillator's sound is passed or stopped,

Using this mixer allows either noise or tone or both or nothing to be passed to a single amplitude register and so to a precise position in the stereo field.

Sam Coupe Technical Manual version 3.0 | 24
- PITCH -

The pitch of each complete oscillator is controlled by two parameters. These are eight possible octaves per generator and 256 possible tones per octave. By carefully choosing octave and tone register data, a smooth transition is possible from the lowest frequency on this sound of 31Hz to the highest frequency of 7.81KHz.

- MUSIC -

Chromatic scales are possible using the table below. Please note also, that the tone numbers are also valid for the other octaves of the same note although tuning may be difficult towards the lower octaves.

- THE CHROMATIC SCALE
NB: | All numbers given in decimal.
Note | Tone | Octave | Required | Actual
| Number | Number | Frequency | Frequency
| (decimal) | | (Hz) | (Hz)
Middle C | 33 | 03 | 261.626 | 261.506
C# | 60 | 03 | 277.183 | 277.162
D | 85 | 03 | 293,665 | 293.427
D# | 109 | 03 | 311.127 | 310.945
E | 132 | 03 | 329.628 | 329.815
F | 153 | 03 | 349.228 | 349.162
F# | 173 | 03 | 369.994 | 369.B22
G | 192 | 03 | 391.995 | 391.850
G# | 210 | 03 | 415.305 | 415.282
A | 227 | 03 | 440.000 | 440.141
A# | 243 | 03 | 466.164 | 466.418
B | 5 | 04 | 493.883 | 494.071
C | 33 | 04 | 523.251 | 523.013

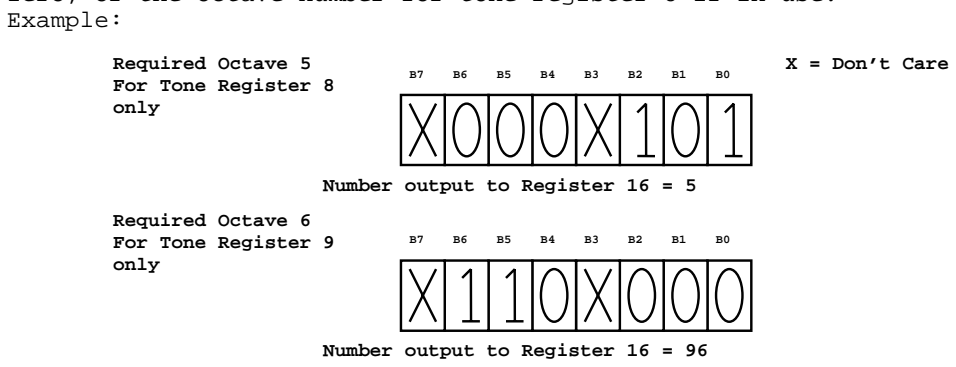
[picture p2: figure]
Example:; Required Octave 5 For Tone Register 8 only; Required Octave 6 For Tone Register 9 only; Number output to Register 16 = 5; Number output to Register 16 = 96; X = Don’t Care
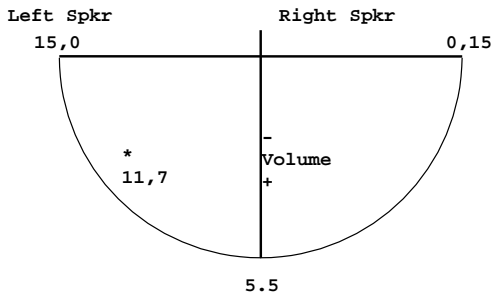
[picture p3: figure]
Left Spkr; Right Spkr; - Volume +

Sam Coupe Technical Manual version 3.0 | 25
- OCTAVE REGISTERS -

Register 16 is an octave register altering the octave of tone registers 8 and 9. This is made possible by only using three bits per tone register to select the required octave.

Thus 2x2x2 gives us eight possible octaves as previously mentioned. So, to access the octave register for tone register 8, we must supply a number (0-7) to the lower 3 bits of register 16. If we needed to access the octave for tone register 9, we would then need to supply a number between 16 and 64 making sure that the first four bits DO-D3 contain zero, or the octave number for tone register 8 if in use.

- AMPLITUDE REGISTERS -

Any data sent to a particular amplitude register can precisely control the position of a sound in the stereo field.

This is made possible by using the same technique as for the octave register. The only differences being that this time 4 bits are used to convey the volume of each channel, and the two 'halves' of the binary number refer to two channels (left and right) instead of two separate tone registers.

This would place the sound towards the left side of the stereo field.

==== Right === ==== Left ====

B7 | B6 | B5 | B4 | B3 | B2 | B1 | B0
Volume 11 required
on left channel.
Volume 7 required
on right channel for
amplitude register 2

Imaginary Position
Of Sound Emanating
From Speakers in
Stereo Field

Sam Coupe Technical Manual version 3.0 | 26
- NOISE GENERATORS -

We have two noise generators again controlled by one register. The operation is very similar to that of the octave registers, but this time only 2 bits are used per noise generator. This gives 4 possible noise clock frequencies. Three of these options are preset - namely 0=31.25KHz, 1=15.6KHz and 2=7.8KHz. The fourth option (External) is controlled by the frequency of Generator 0 in the case of Noise generator 0 or Generator 3 in the case of Noise Generator 1. Using these generators, we are able to vary the 'pitch' of the noise and/or tone. If only continuously controllable noise is required, the relative tone mixer bit is disabled, but the relative noise mixer bit enabled. This technique is called using a tone generator to "Modulate" the frequency of the noise.

- ENVELOPE REGISTERS -

The envelope controllers can be found on registers 24 and 25.

Bit 0-Controls whether the envelope that is set up is mirrored in the left or right channel. (This can be useful to generate a sense of movement without writing to the amplitude registers).

Bits 3,2,1-Set envelope shape. These three bits select an envelope shape from the table found in Fig 3. in the Philips sound chip data sheet.

Bit 4-Controls resolution of envelope if repeated very quickly. 16 levels of resolution controlling envelope modulation are available for repetition up to 977Hz and 8 levels for repetition rates above 977Hz.

Bit 5-This bit controls whether the envelope registers are controlled by generators 1 or 4. If this bit is reset(0), then the internal clock is used to control the shape of the envelope. If this bit is set(1), then the external clock is used(AO) to control the envelope.

Bit 6-is not used.

Bit 7-is used to enable or disable the operation of the envelope controller. Note that this bit should be set (1), the enable envelope control.

Sam Coupe Technical Manual version 3.0 | 27

THE SAM COUPE SOFTWARE

MEMORY

Several memory arrangements are possible with the Coupe, with various advantages and disadvantages, and each of these sections is discussed in detail. The screen mode and the location of screen memory are perhaps the first factor to consider.

- SAM COUPE MEMORY MAP -
0FFFFH | ROM1 OR PROGRAM,
VARIABLES OR SCREEN
0C000H | PROGRAM, VARIABLES
OR SCREEN
0B000H | START OF
CHANNELS | CHANS
05CB6H | SYSTEM
VARIABLES | SVARS
05A00H | KEYBOARD TABLE
058E0H | KTAB
DEF KEY | DKLIN
BUFFER | DKBU
05800H | LINE INTERRUPT
COLOUR TABLE
05600H | LINICOLS
PALETTE
TABLE
055D8H | PALTAB
UDG
PATTERNS | UDGS
CHR$ (127 - 168)
05490E | CHARACTER
PATTERNS
CHR$(32 - 127)
05190H | CHARS

Sam Coupe Technical Manual version 3.0 | 28
05120H | PAGE ALLOCATION
OF 33 BYTES.
(1 per 16K PAGE+FFH)
05l00H | ALLOCT

050FFH

GENERAL-PURPOSE
BUFFER SPACE
04F00H | MACHINE
STACK | SP

FLOATING POINT STKEND
CALCULATOR
STACK
04D00H | STKBQT
04C00H | FARLDIR BUFFER
04B50H | HDL
TAPE HEADERS
04B00H | HDR
BASIC STACK FOR | STKBQT
GOSUB/DO/PROCED | BASSTK
URES
BSTKEND
SPARE FOR HEAP
OR BASIC STACK
SYSTEM HEAP. | HEAPEND
2.7K AVAILABLE
DOESN'T PAGE
04000H | HEAPST

ROM 0

00000H

Sam Coupe Technical Manual version 3.0 | 29
- SCREEN MEMORY LOCATION -

A complete screen takes 6.75K in mode 1 and 12K in mode 2 (not including a 2K gap between pixel and attribute data). In these modes the memory containing the screen can be switched in at any 16K boundary. The paging system means that the other 16K RAM page in the same half of memory will page at the same time as the page containing the screen. Modes 3 and 4 require 24K and thus two 16K pages. You can either leave the screen memory permanently paged in or just page it in when you want to read it or write to it, providing your screen handling code is paged in at the same time! The ROM switches in the screen as it requires, in sections C and D of the memory map (8000H).

- THE STACK -

The ROM normally keeps the machine stack and system variables in section B at 4000H-5CD0H, so that they are not paged out when the screen, Basic program or variables area are paged in in the top half of memory.

ROM

ROM0 is normally switched into section A of the memory map. ROM1 is normally switched out until it is needed; when in use it is located in section D. Jump table routines in ROM0 that need ROM1 will page it in automatically, use it, and then restore its previous status.

- USE OF ROM SUBROUTINES -

The ROMs usually expect the stack to be in section B, and many routines require the system variables in the same area to be intact. However, if you wish to use this area for your own code, you can page out the system variables and use the ROM routines indirectly via JSVIN (see later). This routine will switch the system variables back in temporarily while the ROM routine of your choice is executed. The screen will be temporarily switched into section C and D if required, but your code can usually be located in the same area. Naturally, ROM0 must be enabled if you want to use the jump table, but you could page it out most of the time.

For example, you could load your machine code, disable interrupts, switch out ROM0, switch new RAM into section A/B, and use it for your program. You could provide some code to handle maskable and/or non-maskable interrupts, if desired. Before using a ROM routine, enable ROM0 from somewhere outside section A, and use JSVIN to call the routine you want. If you switch the page your code is currently executing in, remember that the next instruction will come from the new page!

Sam Coupe Technical Manual version 3.0 | 30
- USING SCREEN MODES 3 AND 4 -

The arrangement of screen memory in modes 3 and 4 makes plotting a pixel very simple. A method similar to that used by the ROM for mode 4 (256*192, 16 colour) is shown below. On entry, L and H are the X and Y coordinates (0,0 at top left) and D has the colour to use in both its nibbles (e.g. D=77H for colour 7). H and L are returned unchanged (convenient, for example, during line drawing).

PLOTLH: SCF
RR H
RR L
LD A,(HL)
JR C,PLOTODD ;jr if odd pixel

XOR D
AND 0FH
XOR D | ;mix left nibble of D with right nibble
;tread from screen
LD (HL),A
ADD HL,HL | ;restore entry HL
RET

PLOTODD: XOR D
AND 0F0H
XOR D
LD (HL),A
ADD HL,HL
INC L | ;restore entry HL
RET

The address of the next scan line can always be obtained by adding 128 to the current screen address.

The screen can be easily moved left or right by 1 pixel using the RLD and RRD instructions provided by the Z80. LDIR and LDDR can be used for
2, | 4, | 6 | etc. | pixel | moves. | The | ROM | subroutines | support | most
possibilities.
- PALETTE SWITCHING -

The ROM interrupt routine sets up the palette registers (CLUT) at the start of every frame, using one of two tables of 16 bytes at PALTAB, and switching between them to give flashing colours. It is a good idea to keep these tables up-to-date with the current colours, even if you do not want to use the ROM routines, because the palette registers themselves cannot be read. Software entered via MNI would find an accurate PALTAB useful when doing screen dumps or palette alterations.

Sam Coupe Technical Manual version 3.0 | 31

The ROM can also change a specified palette memory to a given value at a specific scan line, allowing many more than 16 colours to be displayed at once. If only a single change is made per scan line, it will occur during the scan flyback time and no flicker will occur in the display. In the Coupe's striped start-up screen all the stripes are actually palette colour 0 - but palette memory 0 is being altered.

If more than one palette change is programmed to occur at a given scan line, the later changes will occur as the picture is displayed, and this can cause flicker if the colour being altered is on-screen at that particular location. Up to 127 changes can be made per frame. If you wish to provide your own routine this can be added using the line interrupt vector address (LINIV), or by switching out the ROM.

- THE PAGING SYSTEM -

The paging system makes it possible to page in any address so that there are at least 16K bytes above it before FFFFH is passed. This means that when dealing with data structures less than 16K long, once the start of the data is paged in there is no need to take special precautions to ensure pointers do not "fall off" the end of memory. The ROM normally uses memory sections C and D as a “rotating window" onto memory and keeps system variables and the stack in section B. For example when the next Basic line is pointed to by adding a number to HL (adding current line length to current line start) code similar to that below checks to see if HL has moved out of section C into section D. If so, the page value is increased and HL is adjusted to point to the same actual byte, at an address 4000H lower, in section C. The whole line can then be dealt with fairly simply since no further checks of HL need be made until the next line is looked at.

BIT 6,H
JR Z,LAB1

IN A,(HMPAGE)
INC A
OUT (HMPAGE)
RES 6,H

LAB1: ETC.

Here there is no danger of the lower 5 bits of HMPAGE being incremented past 1FH to corrupt the upper bits, since the last line of program has a terminator. This will be the case with most other data structures you are likely to want to use.

Sam Coupe Technical Manual version 3.0 | 32
- ROM RESOURCES -

The ROM should be used via the documented fixed locations or the jump table to avoid problems with new ROM issues. References are made to ROM 1.0 and ROM 1.2. All production machines contain ROM 1.0, however a free upgrade will allow users to change this to ROM 2.0, which is the production version of ROM 1.2. Production machines will be fitted with ROM 2.0 by mid 1990. The ROM version installed can be determined by: PRINT PEEK 15, and dividing the value displayed by 10.

FIXED ROUTINES NEAR THE START OF LOWER ROM

0000 MACHINE INITIALISATION
0004 POP HL | Call here to return your own address in HL.
0005 JP (HL)

The two instructions above provide the ability to (effectively) use CALL within relocatable code. For example.

CALL 0004H | ;get address of HERE in HL
HERE | LD | DE,THERE-HERE
ADD HL,DE | ;add displacement to get
;address of THERE
CALL 0005H | ;effectively, CALL THERE
| etc.
THERE | RET

The method above corrupts HL and DE, but it can be adapted to use the alternate register set or IX or lY if desired.

0006 JP (JY)
0008 ERROR HANDLER
000F ROM VERSION NUMBER
0010 Print char in 'A' register to current stream. The 'K' and 'S' channels respond to control codes for PEN, PAPER, OVER, INVERSE, FLASH, delete, left, right, up, down, AT, TAB and carriage return.

0013 Print BC bytes starting from DE, using current stream. 0016 JP (BC)
0018 Get current character from Basic line.
0020 Get next character front Basic line.

0028 Call floating point calculator. The example multiplies the top two numbers on the floating point calculator stack, then divides the result by 10 and swops top and third no.s.

| RST 28H | ;a,b,c,d
| DB MULT | ;a,b,c*d
| DB STKTEN | ;a,b,c*d,10
| DB DIVN | ;a,b,c*d/10
| DB SWOPl3 | ;c*d/10,b,a
| DB EXIT

Sam Coupe Technical Manual version 3.0 | 33

The operation codes used are different from the Spectrum's, and more numerous; see the separate section on the floating-point calculator. Note: The vector address RST28V makes it possible to translate any operation code into another before the operation is performed.

002B | DJNZ 002B | Useful for uncontended timings.
002D | JP (IX)
0030 | USER RST. Intended for debugging etc. JPs to the
address in "RST3OV".
0033 | JP (DE)
0035 | DJNZ 0035H | Useful for timing.
0037 | RET
0038 | MODE 1 INTERRUPTs
005C | OUT (HMPR),A
| JP (HL)
005F | LD A,B | | Useful for timing.
| OR C
| DEC BC
JR NZ,005F
| RET
0066 | NON-MASKABLE INTERRUPTS
RAM contention means that ROM routines usually | run | slightly faster
than identical RAM routines. If you are executing | the Z80's block
instructions on large blocks, and | speed | is important, it might
be worthwhile to call the routines below:
008F | LDIR: | RET
0092 | LDDR: | RET | (block moves run about 8% faster in ROM)
0095 | CPIR: | RET
0098 | CPDR: | RET
009B | OTIR: | RET
009E | OTDR: | RET

JUMP TABLE AT 0100H

Sometimes conditions for entry a few bytes past the start of a routine are given, as well as the usual entry conditions to the routine; where this is done, you can read the routine address from the jump table, add a displacement, and enter part-way through (for example using CALL HLJUMP). The documented entry conditions will remain constant.

When routines are described as "generating an error” this means that error handling (using RST 08H) will clear the machine stack back to the value held in ERRSP and then do a RET. Normally this leads to an error message being given in the lower screen window, but this can be avoided by PUSHing the address of your own error handler onto the stack, and altering ERRSP (possibly temporarily) to hold the current Stack Pointer. When you gain control, ERRNR will hold the error number (see the list in the Basic manual).

Sam Coupe Technical Manual version 3.0 | 34

JSCRN
(0100H)

Select screen held in the C register (1-16). Equivalent to Basic's SCREEN command. An error is generated if the screen is not open. This Jump Table entry is not available in version 1.0 of the ROM

JSVIN
(0103H)

Call parameter word with system variables page switched in. HL', DE', BC' and F are corrupted, and interrupts are enabled, before the parameter address is called. All other registers are passed intact. On exit, all registers except AF' have the values left in them by the called routine. The original status of HMPR is restored. For example:

CALL JSVIN
DW JGETINT
LD (STORE),HL etc.

JHEAPROOM
(0106H)

Reserve BC bytes in the system heap. This is always paged in; it is in the same page as the stack and the system variables, paged into memory area B. On entry, BC=bytes to reserve (if BC is positive) or bytes to release (if BC is negative). On exit, if the carry flag is set the call was successful, and DE points to the old HEAP END (the start of the reserved space), HL points to the new HEAP END (one byte past the end of the reserved memory), and BC is unchanged. If the carry flag is reset, not enough space was available, and HL holds the amount that the request exceeded the available space by.

JWKROOM
(0109H)

Open BC bytes in workspace (a temporary work area, cleared before each Basic statement is dealt with). On exit, DE points to the reserved space, starting in section C of the memory map, paged in. HL points one byte past the end of the space, provided it is less than 16K long. A and BC are unchanged.

JMKRBIG
(010CH)

Open A 16K pages and BC bytes at HL in section C of the memory map. BC must be 0-3FFFH. This routine can be used to
open space before the Basic program, inside it, | in the
variables area, or the workspace. If there is | not
sufficient space, an error will be generated. On | exit, HL
points to the space and DE points to the end | of the space
(if the space <16K).

Sam Coupe Technical Manual version 3.0 | 35

JCALLBAS
(010FH)

Call BASIC subroutine at line HL. When RETURN is used, or any error occurs (for example, STOP, variable not found, etc. - even "OK" counts, in this case), your machine code will be re-entered. On return, A holds an error code, or zero if there was no error (and the zero flag will be set if there was no error). When your machine code finally does a RET to return to Basic, the statement that called the code in the first place, such as CALL 54000 or PRINT USR 54000, will be completed, but then the program will carry on at the statement after the RETURN in the Basic subroutine, or after the point where an error occurred, because Basic's notion of its current line and statement have been altered during the subroutine execution.

To return to the statement after your CALL, or anywhere else in the program for that matter, read the values from SUBPPC and PPC before using any Basic subroutines, then INC the SUBPPC value and place it in NSPPC, and place the old PPC into NEWPPC. This will cause a GO TO of the specified line and statement when your machine code RETs.

JSETSTRM
(0112H)

Set the stream specified by the A register (FBH-10H).
FBH=channel 'B' (Always) | Printer binary output.
FCH=channel '$' (Always) | Output to a string.
FDH=channel 'K' (Always) | Lower screen I/O.
FEH=channel 'S' (Always) | Upper screen I/O.
FFE=channel 'R' (Always) | Output to edit line.

00H=channel 'K' (Usually)
01H=channel 'K' (Usually)
02H=channel 'S' (Usually)
03H=channel 'P' (Usually) Printer text output.

JPOMSG
(0115H)

Output message number A from table at DE. Zero gives the first message. Each message should have bit 7 set on the last character. Characters 0-31 should not be included. The current output stream is used.

JEXPT1NUM
(0118H)

Syntax check/evaluate a numeric expression. During syntax checking an invisible 5-byte form of any literal numbers is inserted. During run time the result of the expression is left on the floating point calculator stack.
JEXPTSTR
(0116H)

Syntax check/evaluate a string expression. See JEXPT1NUM.

JEXPTEXPR
(0llEH)

Syntax check/evaluate an expression. See JEXPT1NUM. These three routines can be useful in extending the Basic interpreter.

JGETINT
(0121H)

Unstack number from calculator stack into HL. BC holds a copy of HL, and A holds a copy of L. An error is generated if the rounded number is not in the range 0-65535.

Sam Coupe Technical Manual version 3.0 | 36

JSTKFETCH
(0124H)

Unstack last value from calculator stack to AEDCB. If the value is a floating-point number, the 5 bytes are in CPC/Spectrum format. If the value is a whole number between 0 and 65535 (which may be negative) it may be in a special form where A=O (showing special form), E=SGN (0=positive, FFH=negative} and D and C are less and more significant bytes. If the value is a string, A holds the page the string text starts in, DE holds the start address of the text start within the page (8000-BFFF), and BC holds the string length.

JSTKSTORE
(0127H)

Stack AEDCB registers on the calculator stack. On exit, HL holds the new STKEND, and AEDCB are unchanged. No other registers are altered.

JSBUFFET
(012AH)

Unstack the details of a string from the calculator stack and copy the text to a buffer in the system page in section B of the memory map. Paging is undisturbed on exit, no matter where the string is copied from. Generates an error if the string is more than 255 characters long, or the null string. On exit, DE points to the start of the buffer and BC holds the string length. The A register holds a copy of C.

JFARLDIR
(012DH)

Copies bytes from page A, offset HL to page C, offset DE.
Copies | (PAGCOUNT) | 16K | pages | and | (MODCOUNT) | bytes
(MODCOUNT=0000-3FFF), paging as needed. The paging state on entry is unimportant, and is unchanged on exit. Since the routine copies via a buffer, it is usually possible to write a faster, more specialised routine if the required paging can be arranged.

JFARLDDR
(0130H)

A LDDR version of FARLDIR.

Sam Coupe Technical Manual version 3.0 | 37
JPUT | Screen modes 3 and 4 only. Place a block of data on
(0133H) | the screen at given coordinates.

On entry, C holds the x coordinate (bit 0 is not significant, since the data can only be aligned to byte accuracy). The x-range is 0-255, whatever the MODE.

The B register holds the y coordinate, with 0 at the top of the screen and 191 at the bottom.

The HL register points to the data to use; the first and second bytes of the data specify width in bytes and height in pixels, followed by 811 bytes for the top scan of the block, all bytes of the second scan, etc.

The A register determines the method of placing the data on the screen. 0=overwrite with INVERSE option, 1=XOR, 2=OR, 3=AND, 4=overwrite (with no INVERSE option - faster), 5=mask. The mask option requires a second block of data the same length as the first (excluding the first 2 bytes of the first block) pointed to by HL', with bits set for "unmasked" and reset for "masked".

This allows a complex shape, perhaps with holes in it, to be placed on a background without border effects. If the shape hangs off the bottom of the screen, it will be "trimmed' to fit. If the data overlaps the right border of the screen, it will wrap round to the left, but 1 scan lower.

Both HL and HL' (if used) must point to data that will be available for use; since JPUT will temporarily switch in the current screen (using CUSCRNP, or at least the contents of that address) at 8OOOH, the data must be located at 4000-7FFFH, or EOOO-FFFFH in the screen page. JPUT also needs to use the system variable CURP (or a byte at that address) as a temporary store, and it will read INVERT to determine INVERSE status, where this is an option. JPUT should run rather faster than Basic's PUT, since Basic has to move data from the variables area.

Unlike attribute colour systems, the colours to be used are implicit in the block data, although methods 0-3 allow an INVERSE option. The restriction that blocks must be put down at even pixel boundaries is to keep the speed high. If you wish to place blocks at 1-pixel intervals, it is possible to prepare two versions of the same graphic, with the data displaced by 1 pixel in one of them, in order to get the required effect.

In version 1.0 ROMs there is an error in JPUT, but you can
get the same effect by using: PUSH AF: CALL 3A7BH: POP AF:
CALL 2DACH instead of CALL 0133H. If the ROM version number (PEEK 15) is not 10, you must use 0133H.

Sam Coupe Technical Manual version 3.0 | 38
JGRAB | Screen modes 3 and 4 only. Store a block of screen
(0136H) | data from given coordinates to a buffer.

On entry, C holds the x coordinate (bit 0 is not significant) and the x-range is 0-255 whatever the screen MODE. B holds the y coordinate, with 0 at the top of the screen and 191 at the bottom. E holds the block width in bytes, and D holds the length in pixels. On exit, DE points to the start of the block in the current screen page (specified by CUSCRNP); the first byte is always zero, the next byte is the width in bytes, the next byte is the length in pixels, and the following bytes store the block, scan line after scan line. BC holds the block length, including the a header bytes. Since the area is stored in the "spare" 8K following a MODE 3/4 screen, the length of the data must be a little under 8K, at the most. JGRAB requires temporary storage at the variable CURP (or storage at that address) and it will read CUSCRNP in order to temporarily switch the screen in. If the GRABed area hangs off the bottom of the screen, it will be trimmed as needed.

JPLOT
(0139H)

Plot pixel at x coordinate in C and y coordinate in B, except when the MODE is 3 and FATPIX 0 is in force (THFATT will be zero); in which case use HL as the x coordinate (0-
511) and plot a "thin" pixel. The y-axis has 0 at the top and 191 at the bottom in all cases. There is no control to prevent you plotting beyond the bottom of the screen.

JDRAW
(013CH)

Draw a line from the current position C (or HL if "thin" pixels are in Use, according to THFATT) pixels horizontally and B pixels vertically. D=1 for down (or for no y movement) and FF for up, E=1 for right (or for no x movement) and FF for left. The colour and OVER and INVERSE state come from the temporary graphics variables. The screen used comes from CUSCRNP. An error is generated if the line is drawn over the screen edge.

JDRAWTO
(013FH)

Draw a line from current position to point C,B (or point HL, B if "thin" pixels are in use). The y axis has zero at the top and 191 at the bottom. Colours etc. come from the temporary graphics variables.

JCIRCLE
(0142H)

Draw circle at C,B radius A. If "thin" pixels are set, HL should hold an offset from the left-hand screen border (in pixels). This allows a circle to be placed anywhere on a mode 3 screen even though the x coordinate is limited to 1 byte. The y axis has zero at the top. Colours etc. come from the temporary graphics variables.

Sam Coupe Technical Manual version 3.0 | 39

JFILL
(0145H)

Modes 3 and 4 only. Uses the 16*16 pixel pattern at DE to fill an area starting at coordinates C,B. The y axis has zero at the top. If DE holds zero, a "solid" fill with the current PEN (from M23INKT) is performed. Otherwise DE can have any value (but values 000l-3FFFH will use the ROM as a pattern!). If A=0 then a preliminary transfer of the screen memory to a scratchpad area (6K long, immediately after the 24K screen memory) is made; you will need to make A=0 for at least the first fill you use. Later fills on the same screen over the same colour can make A non-zero for greater speed.

If you are using MODE 3 with "thin" pixels, HL should hold a byte offset from the left-hand screen edge for the point to start filling at. This allows any part of the screen to be filled, despite the x coordinate being limited to one byte.

The pattern data pointed to by DE has 8 bytes for the top row, 8 bytes for the next, etc. so 128 bytes are needed. Each nibble controls colour for 1 pixel in mode 4 or 2 pixels in mode 3.

JBLITZ
(0148H)

Execute a string of graphic commands BC long at DE. DE can be anything from 4000H to FFFFH, and BC anything from 0 to FFFFH (JBLITZ will page if required). PLOT, DRAW, DRAW TO, CIRCLE, OVER, INK, CLS and PAUSE commands can be included in the string. They are handled at a higher level than JPLOT, JDRAW and JCIRCLE; the floating point calculator and special Basic variables can be used for offset and scaling. The use of numerous system variables makes having the system variables paged in hard to avoid. x coordinates and moves of 0-255 only are allowed; i.e. only half the screen is easily usable in MODE 3 with FATPIX 0 selected. The coordinate system used is the same as that used by Basic; e.g. bytes 01 00 00 would act like PLOT 0,0 in Basic and be modified if XOS or YOS were altered. To perform a RELATIVE DRAW:

00 or FF give the SGN of an x movement (00=positive, FF=negative), followed by the x movement, followed by the SON of the y movement and the y movement. If movements are negative, they are stored as 256-move.

PLOT: | 0l | followed by x,y
DRAW TO: | 02 | followed by x,y
CIRCLE: | 03 | followed by x,y,r
OVER: | 04 | followed by 0-3
PEN: | 05 | followed by 0-17
CLS: | OG | followed by 0-1
PAUSE: | 07 | followed by 0-255

The easiest way to prepare the data for JBLITZ is to use RECORD in Basic and then POKE the string where you need it.

Sam Coupe Technical Manual version 3.0 | 40

JROLL
(O14BH)

Modes 3 and 4 only. Move part of screen left, right, up or down. The screen area must be an even number of pixels across. A horizontal move by 1 pixel or any even number of pixels is possible. A vertical move by any number of pixels is possible. Wrap-round is optional; it uses the area immediately after screen memory as a buffer. On entry, A is 00 if a SCROLL (no wrap) is wanted, or FFH for a ROLL (with wrap). B holds the pixels to move by, C is a direction code (l=left, 2=up, 3=right, 4=down), D holds length of block in pixels and E holds width of block in pixels (bit 0 is non-significant). HL holds the coordinates of the top left-hand corner of the block to be moved, L holding the x coordinate (range 0-255, whatever the MODE) and H holding the y coordinate with 0 at the top of the screen. JROLL checks the
MODE | system | variable, | copies | the | permanent | graphics
variables onto the temporary ones, and uses M23PAPT as the background colour for new screen generated by SCROLL. The routine uses CURP and TEMPPB3 in the system variables, and up to 0181H bytes at 4D00H to store "unrolled" code loops.

JCLSBL
(Ol4EH)

Clear entire screen if A=0, else clear upper screen.

JCLSLOWER
(0151H)

Clear lower screen. Also selects channel K (lower window input/output).

JPALET
(0154H)

If A=FFH, put colours BC in PALTAB as main and flashing colours for palette colour E. (Make B=C for no flashing). Colours should be 0-127, palette entry 0-15. If A is non-zero, it is a y-coordinate to alter the palette at. PALTAB is not altered; instead an entry is made in the line interrupt colour table.

JOPSCR
(0157H)

OPEN SCREEN number C in mode B. The pages required are located in the Page Allocation Table and reserved, and an entry is made in SCLIST. The screen number must be 2-16, and it must not be already open, or an error is generated.

JMODE
(015AH)

Set screen MODE that is in the A register (0-3 gives MODEs 1-4).

JTDUMP
(Ol5DH)

Do a text screen dump (if dump utility installed).

JGDUN?
(0160H)

Do a graphic screen dump (if dump utility installed). The system variables documented in the Basic manual control the area dumped and its magnification.

Sam Coupe Technical Manual version 3.0 | 41

JRECLAIM
(0163H)

Reclaim (close up) BC bytes at HL (8000H-BFFFH). Can be used to close up memory before a Basic program, within it, or in the variables area or workspace. BC must be less than 16K; if you want to reclaim a bigger space, call one byte from the start of the routine, with A holding number of 16K pages to reclaim, in addition to the space specified in BC.

JKBFLUSH
(0166H)

Flush keyboard buffer.

JREADKEY
(0169H)

Read keyboard, flush butter (like INKEYS). Z/NC if no key pressed, else NZ/CY and A=key value (ASCII).

JWAITKEY
(016CR)

Read next key into A from keyboard buffer. Wait for a key to be pressed if needed.

JBEEP
(0l6FH)

Make a beep DE-1 cycles long at period HL*8 T states.

JSAVE
(0172H)

Save a block CDE bytes long starting at HL (switched into section C). C holds the number of 16K pages, and DE holds the length MOD 16K. Make A register first byte saved, (FFH for 'data block', 01 for SAM 'header', 00 for spectrum header). If SLDEVT (see system variables) holds "T", the SAVE will be to tape-if it holds "N" the SAVE will be to the Network. SLNUMT controls the save speed to tape (112 is standard speed).

JLOAD
(0175H)

If the carry flag is set, LOAD CDE bytes to HL (switched into section C of the memory map). If the carry flag is reset, do a VERIFY. The A register holds the type of data to deal with (FFH=data block, O1=SAM or Spectrum header, 00=spectrun header). If SLDEVT holds "T", tape will be used; if "N", the Network. Varying input tape speeds are handled automatically. The routine returns with carry set if the operation was successful; otherwise there has been an error.

JLDVD
(0178H)

If the carry flag is set, LOAD CDE bytes of data (not header) to HL. If the carry flag is reset, do a VERIFY. Use disk, tape or Net according to the contents of SLDEVT. An error is generated if the operation fails.

Sam Coupe Technical Manual version 3.0 | 42

JEDGE2
(017BH)

Waits for 2 signal transitions on EAR, returninq in A and C the number of 47-T state units taken. On entry, B should hold the current EAR status in bit 6, bit 3 should be set, and the other bits should reflect what you want sent to the BORDER port when there is a signal transition. Bits 2-0 will be reversed on every transition. The D' register should hold a value that determines the length of a pause between finding one transition and looking for another (this avoids double counts when the tape signal has buzzy edges). For standard speed tapes, D' should be about 46H, JLOAD sets D' according to tape speed. Interrupts should be disabled for accurate results.

The routine returns Z if it had to wait too long (256 units), NC if ESC was pressed, and CY if okay. Entry 2 bytes from the start avoids the initial zeroing of the C register which is used as a counter; entry 6 bytes from the start waits for only 1 signal transition on EAR. On exit the B register holds a new value suitable for another call to the routine, and A and C both hold the counter value. Note: In version 1.0 ROMs this jump table entry incorrectly has bit 15 of the address set. You should read the address at O17CH, reset bit 15, and CALL that address.

JSTRS
(017EH)

Create ASCII version of number on floating-point calculator stack in buffer at 5BA0H. On exit, DE holds 5BA0H and BC holds the number of characters in the buffer.

JSENDA
(0181H)

Send the byte in the A register to the parallel printer. The system variable at 5A10H is read to obtain the port to use, and the routine loops until the printer is ready before sending the byte and then returning. If ESC is pressed, an error will be generated. Uses A and BC only.

JUMP TABLE ENTRIES INTRODUCED AFTER ROM 1.0

JNCHAR
(0184H)

Call SCREEN$ subroutine. Try to match the character at line D, column E on the screen with any character in the main character set (pointed to by CHARS) or any character in the set pointed to by UDG. On exit, the carry flag is set if the search was successful, in which case A holds a character code of 20H-7FH (32-127) if the character was found in the main set, or 80H-7FH (128-168) if the character was found in UDG set. If the carry flag was reset, A=0 and the search failed.

JGRCOMP
(0187H)

Subroutine used by graphic dump utility.

Sam Coupe Technical Manual version 3.0 | 43

JGTTOK
(Ol8AH)

Try to match potential spelled-out keyword pointed to by DE in a list of keywords at HL+1. The list should be in upper case, with bit 7 set on the last letter of each keyword. The A register should hold the number of words in the list, plus
1. On exit no match was found if the zero flag is set. If a the zero flag is reset, the A register holds the entry number in the list (1 or more), HL points to the start of the original word and DE points just past the end of it.

JCLSCR
(018DH)

Close screen number held in the C register.

- CHARACTER SET -

The character set from CHR$ 32 to CHR$ 130 is stored in compressed form in ROM1 and loaded into RAM in the system variables page when the machine is turned on. CHR$ 131-168 are initially defined as blanks, although CHR$ 128-143 are displayed as block graphics unless "BLOCKS 0" has been set. (The block graphic shapes are generated as needed - the character set itself does not contain them). Characters apart from block graphics occupy a 6*8 matrix, making then suitable for display at 6-pixel or 8-pixel intervals.

Character definitions occupy 8 bytes, from top row of pixels to bottom row. The left and right columns of pixels of this 8*8 block are not used when printing is at 6-pixel intervals. The character set base address is 5190H, and space is available for CHR$ 32 to 168 in one continuous block. An additional system variable, HUDG, can be set up to point to definitions for CHR$ 169-254, but standard designs for characters 128 to 168 are supplied (file 'font') which includes a full set of foreign characters which match the accented characters on most printers. Their use is recommended so that software can easily be converted for use abroad.

- VECTORS -

These allow important ROM routines to be intercepted by the user. They contain addresses which will be called if (and only if) the most significant byte is non-zero. This gives the option of RETurning (perhaps you decide not to handle a particular case), or discarding the return address and turning the vector into effectively a JUMP.

Several programmers might want to use the same vector. If your programs simply overwrite vectors they are likely to be incompatible with future utilities from MGT and other software suppliers. We recommend that your programs save the old vector value. Unfortunately, an automatic linking mechanism that made this very easy had to be omitted front the ROM, but the solution is still fairly simple: for example, to add code to provide some action for the STEP token:

Sam Coupe Technical Manual version 3.0 | 44

;Initialise CMDV but store any existing entry first.
INIT | LD HL,(CMDV)
LD (STORE),HL
LD HL,MYPATCH
LD (CMDV),HL
RET
MYPATCH | CP STEPTOKEN
JR Z,MYP2 | ;JR if we are interested
LD HL,(STORE)
INC H
DEC H
RET Z | ;RET if no address was in CMDV at INIT
JP (HL) | ;let another routine have a go
MYP2 | (Code to provide some action for STEP)
RET

NB All examples are program fragments, not complete programs, and do not, for example, include the above code, which should be included in actual applications.

LIST OF VECTORS

DMPV
(5ADAH)

Called if the DUMP keyword is used in run-time. CHAD points to 0DH or 3AH if just DUMP was used; otherwise DUMP CHR$ was used.

SETIYV
(5ADCH)

SETTY is called when DRAW, PLOT and CIRCLE "decide" what pixel setting routine to use, and itself calls SETIYV if its most significant byte is non-zero. SETIY points the IY register to a suitable routine, and the provision of a vector is intended to allow extra plotting modes, such as dotted lines, to be implemented without all the graphics commands being rewritten. On entry to SETIYV, A holds the current screen mode-1.

On return to PLOT, DRAW and CIRCLE the IY register should point to a pixel setting routine, and only A and HL should be altered otherwise. In mode 4, and mode 3 when "fat" pixels are selected, the value of A on exit is passed to D' by the graphics commands, and can be used to hold the PEN colour if desired.

If you alter SETIYV, as with all the vectors, your routine making just RET will cause the normal ROM routine to be executed. Thus your code might start with a check of the mode to see if it is one you want the ROM to deal with, and RET if so. Otherwise, POP the return address so that the ROM routine is never used, and set IY yourself. The next RET will be to DRAW, PLOT or CIRCLE.

Sam Coupe Technical Manual version 3.0 | 45

The pixel setting routine that you supply the address of in IY should plot the pixel at L,H and return with only AF changed. The coordinate system used has 0,0 at the top left-hand comer of the screen. You may want to take note of the current OVER, INVERSE and PEN settings. (In which case you may find it speeds things up if, like the ROM, you set IY to a different routine for some options). The routine should end in JP (IX), not RET.

PRTOKV
(5ADEH)

Print a token. A=token code to expand and print as ASCII.

MNIV
(5AE0H)

Non-maskable interrupt. Normally holds the address of a routine that returns to Basic when the BREAK button is pressed. NMIV switches in the system page temporarily, and provides its own stack there, whatever the paging state when the interrupt was generated. On entry, the LMPR status when the NNI occurred is stored in NMILRP, the Stack Pointer when NMI occurred is stored in NMISP, and the AF and HL registers have already been PUSHed onto the stack in use when NMI occurred (which may be paged out).

FRAMIV
(5AE2H)

Called by the frame interrupt 50 times a second. All main registers can be used.

LINIV
(5AE4H)

Called by the line interrupt, which is generated when the value in the line interrupt register matches the scan about to occur. This vector can be used to alter the palette, change screen or screen mode, etc. in mid-screen. To synchronise such changes with the scan flyback, it is possible to wait for a change at the HPEN port to show that the scan number has just changed. (This will fail if a light-pen is connected, however). All main registers can be used.

COMSV
(5AE6H)

Called by COMMS interrupt.

MIPV
(5AE8H)

Called by MIDI input interrupt. On entry, the A register has just been read from the MIDI IN port.

MOPV
(5AEAH)

Called by MIDI output interrupt.

EDITV
(5AECH)

Called before the editor is used for editing a line or INPUT.

RSTOBV
(5AEEH}

Called early in error handling, with A=error code. The alternate registers have been selected, CHAD and CHADP have been copied to XPTR and XPTRP, DE points to the error code that follows RST 08H, and an address 1 byte past that code is on the stack, underneath the return address to the error handling routine. No clearing of stacks has been done at this stage.

Sam Coupe Technical Manual version 3.0 | 46

RST28V
(5AF0H)

Called by floating point calculator with A=next code in the list that follows a RST 28H instruction. DE points to the end of the floating point calculator stack. On exit, the IX register should be unchanged, and DE should point to the end of the floating point calculator stack. (This may be different from the entry value, if items have been added, discarded or combined). See example below.

RST30V
(5AF2H)

User RST. Jumped to (Not called like the other vectors) by RST 30H. (ROM0 uses RST 30H to provide a "CALL ROM1" facility, but this only applies to RST instructions used inside ROM0). All registers are passed intact.

CMDV
(5AF4H)

Called with the A register holding the code of the character about to be syntax checked or executed (normally a command code). Can be used to add commands, or modify the action of the existing ones.

EVALUW
(5AF6H)

Expression evaluator. Called with A=current character in expression; can be used to add new functions.

LPRTV
(5AF8H)

Called as each character code above 127 is handled by the printer driver, when channel "P" is being used.(More complete control can be obtained by altering the "P" or "B" channel output address - see below).

On entry to the routine the character code is in the register. For example to transform CHR $ 130 to "A":
INIT: | LD HL,PATCH
LD (5AF8H),HL
RET
PATCH: | CP 130
RET NZ
POP BC | ;JUNK RETURN ADDRESS

LD A,65
RST 1OH | ;PRINT CHARACTER
LD HL,5A70H | ;PRINTER COLUMN VARIABLE
;(SVAR &70)
INC (HL) | ;1 COLUMN RIGHT
RET

Instead of using RST l0H to print the new character(s), you might prefer to use either CALL 0181H (send A to parallel printer) or probably better, call the following code to send the A register to channel "B":

Sam Coupe Technical Manual version 3.0 | 47
CHBOP: | LD HL,(5C4FH) | ;CHANNELS BASE ADDRESS
| LD DE,25 | ;(use 15 to point to "p"
| | ; channel)
| ADD HL,DE
| LD E,(HL)
| INC HL
| LD D,(HL) | ;DE=channel B output address
| EX DE,HL
| JP (HL)
Channel "B" handles all output without fiddling with it; channel "p'. responds to control codes, adds auto-LF etc. and then sends its output to channel "B". something like ESC ;"R"; CHR$ 0 should be sent via the "B" channel. Channel "B" normally outputs using 0181H, but if you use CHBOP rather than O181H directly, it will be easier for others to divert printer output to another device, such as a serial interface. (By altering the output address in the channel).

MTOKV
(5AFAH)

Called if a potential spelled-out keyword is not recognised by the ROM. On entry, DE points to the potential keyword. On exit, conditions should match those of jump table entry
| JGTTOK.

MOUSV
(5AFCH)

Called every frame. when this vector is used, the ROM's own scan of the mouse is bypassed.

KURV
(5AFEH)

Called before the editing cursor is printed (by calling the address in MNOP). ROM1 is on. Could be used to supply a "transparent" or other cursor.

Additional example: Suppose you have a lot of machine code graphics subroutines which require the screen to be switched in at 4000H. It would be nice to modify USR so that any use of the subroutines switched in the required page temporarily; the routine below does this, for machine code located in the top half of memory. INIT is called to alter the floating point calculator ~ vector to point to USRPTCH; whenever the calculator handles a USR, we intercept it, juggle the pages to put the screen at 4000H (taking care with the stack) and call the USR address, stacking BC back on the floating point calculator stack as the result of USR, and returning DE pointing to STKEND and IX unchanged. (All as expected by the calculator).

USRPTCH must be in the system page to guarantee it is resident when the vector is called; the best place is in the system Heap. PART2 must be in the top half of memory, but in any case it is a goad idea to use a short routine in the Heap to call a large routine in another page, since this keeps the Heap train being filled up.

Sam Coupe Technical Manual version 3.0 | 48
INIT | LD HL,USRPTCH
| LD (RST28V),HL
| RET
USRPTCH | CP 45H | ;USR code
| RET NZ | ;keep things simple and ignore
| | ;anyone else who might want to use
| | ;this vector
| POP BC | ;junk RET address
| IN A,(HMPR)
| PUSH AF | ;save current HMPR status
| LD A,1 | ;OK if PART2 in page 1 or 2
| OUT (HMPR),A | ;page in PART2
| IN A,(LMPR)
| AND 0BFH
| OUT (LMPR),A | ;ROM1 off
| CALL PART2
| IN A,(LMPR}
| OR 40H
| OUT (LMPR),A | ;ROM1 on again for RET to calculator
| POP AF
| OUT (HMPR),A | ;original HMPR status restored
| RET
PART2 | LD (STORE),SP | ;we will be switching out the stack,
| | ;so save current SP
| LD SP,TSTACK | ;put a new stack elsewhere (>=8000H)
| PUSH AF | ;LMPR status
| PUSH IX | ;calculator needs IX unchanged
| CALL JGETINT | ;get USR address in BC
| IN A,(VPAGE)
| AND 1FH | ;A=screen page
| DEC A
| OUT (LMPR),A | ;page it in at 4000H
| CALL BCJUMP | ;CALL USR address
| POP IX
| POP AF
| OUT (LMPR),A | ;original LNPR status
| LD SP,(STORE) | ;original SP
| XOR A
| LD E,A
| LD D,C
| LD C,B
| CALL JSTKSTORE
| EX DE,HL
| RET
STORE | DW 0

Sam Coupe Technical Manual version 3.0 | 49

FLOATING POINT CALCULATOR COMMAND CODES

The floating-point calculator performs all the mathematical operations of the Coupe, and many of the string operations. Since it provides a simple way of programming quite complex tasks in a sort of sub-language, it can be very convenient. The calculator is called using RST 28H, followed by a series of command codes (which may have parameters). A special code terminates the list. The data that the calculator manipulates is placed on a special stack that we will refer to as the FPCS. All items are five bytes long. The jump table allows registers to be passed to and from this stack, and the B register is passed into and out of the calculator (see below).

Numbers are held in two forms; the integer form stores whole numbers between -65535 and +65535 as zero, SGN (0 for positive, FFH for negative), less significant and more significant bytes, and a final zero byte. E.g. 80H is stored as 00 00 80 00 00, 4001H as 00 00 01 40 00, -1 as 00 EFF FF FF 00 and -80H as 00 FF 80 FF 00. (Negative values are stored in negated form (65536 minus the number).)

If numbers are in integer form the calculator is often able to use specialised, faster forms of operations such as multiply, subtraction and addition. Numbers outside the -65535 to +65535 have to be held in a different form, as 2 to the power of a number called the exponent, multiplied by another number called a mantissa. The first byte is the exponent +80H, and the other four bytes are the mantissa. This is always between 0.5 and just less than 1, which means that the first bit is always 1, allowing it to be actually used as a SGN bit (0 for positive, 1 for negative).

This scheme allows values between about 1E38 and 1.7E-39 to be stored to an accuracy of 9 or 10 digits. It is important to note that some fractional numbers (such as 1/10) cannot be stored exactly in this binary form (just as, for example 1/3 cannot be represented exactly in decimal form). This means that if you subtract 0.1 from 1 ten times, the result is not exactly zero. This is not a fault - just a limitation of number systems in general, which you should be aware of.

Strings are held as 16K page of string text start, offset of string text start (8000H-BFFFH, LSB/MSB) and string length (LSB/MSB).

In the list below, the action of many of the calculator codes is shown symbolically. Where a command code deals with two numbers (e.g. multiply) the last number on the FPCS is referred to as N2 and the number below that is referred to as N1. If the values dealt with are strings, $2 and $1 are used.

Sam Coupe Technical Manual version 3.0 | 50
00H MULT | N1*N2
01H ADDN | Ni+N2
02H CONCAT | $1+$2 Prepare the concatenated text of $1+$2 in the
| Workspace, and stack the details of this temporary
| string.
03H SUBN | N1-N2
04H POWER | N1^N2
05H DIVN | Nl/N2
06H SWOP | Swap V1,V2
07H DROP | Discard last value
08H MOD | N1 MOD N2
09H IDIV | N1 DIV N2
0AH BOR | N1 BOR N2
0BH Reserved
0CH BAND | N1 BAND N2
0DH NUOR | N1 OR N2
0EH NUAND | N1 AND N2
0FH NOTE | N1<>N2 Comparisons like <> delete the two compared
| values from the FPCS and replace them with 1 or 0
| (true or false).
10H NLESE | N1<=N2
11h NGRTE | N1>=x2
12H NLESS | N1<N2
13H NEQUAL | N1=N2
14H NGRTR | N1>N2
15H SAND | $1 AND N2
16H SNOTE | $1<>$2
17H SLESE | $1<=$2
18H SGRTE | $1>=$2
19H SLESS | $1<$2
1AH SEQUAL | $1=$2
1BH SGRTR | $1>$2
1CH SWOp13 | Swop last value and value 2 below.
1DH SWOp23 | Swop second-to-last value and value below it.

The three command codes below, along with DECB, use a displacement byte to skip backwards or forwards in the list of commands (like GO TO in Basic, or JP in assembly language). The displacement is the distance between the displacement byte and where you want to jump to; if it is greater than 7FH it treated as a backwards jump, for example, FFH is backwards by 1.

1EH JPTRUE | Jump by displacement given in next byte, if the last
| value is one. (The last value is discarded).
1FH JFFALSE | Jump by displacement given in next byte, if the last
| value is zero. (The last value is discarded).
20H JUMP | Jump by displacement given in next byte.

The calculator has a special store called BREG that initially holds whatever the Z80's B register did when the calculator was called. The four command codes below use BREG.

21H LDBREG | Load BREG with next byte.
22H DECB | Decrement BREG and jump by the displacement given in the
| next byte if BREG is non-zero.
23H STKBREG | Put BREG on FPCS as a number between 0 and 255.
24H USEB | Take the next calculator code from BREG.

Sam Coupe Technical Manual version 3.0 | 51
25H DUP | Duplicate top FPCS entry.
26H ONELIT | Stack next byte on FPCS (as a number between 0 and
255).
27H FIVELIT | Stack next 5 bytes on FPCS (as any number).
28H SOMELIT | Stack number of bytes specified by next byte, using
(next byte+1} as the first byte. (This allows many 5-byte values to be stacked at once).
29H LKADDRB Use the next 2 bytes as an address; stack the byte found at that address on the FPCS.
2AH LKADDRW Use the next 2 bytes as an address; stack the word (2 bytes) found at that address on the FPCS.
2BH REDARG | Fiddle with the argument of SIN.
2CH LESS0 | Stack 1 (TRUE) or 0 (FALSE) according to whether the
last value is <0. The last value is discarded.
2DH LESE0 | Stack 1 or 0 according to whether the last value is
<=0. The last value is discarded.
2EH GRTR0 | stack 1 or 0 according to whether the last value is >0.
The last value is discarded.
2FH GRTE0 | Stack 1 or 0 according to whether the last value is
>=0. The last value is discarded.
30H TRUNC | Chop off the digits after the decimal point in | the
last value.
31H RESTACK | Transform the last value to full 5-byte form if | it
isn't already in that form.
32H POWR2 | Calculate 2 to the power of the last value.
33H EXIT | Finish using floating point calculator.
34H EXIT2 | Finish using floating point calculator, and do a RET.
35H Reserved
36H Reserved
37H Reserved
38H Reserved
The | command | codes | below are used to provide | most | of | Basic's
functions:
39H SIN | 4CH EOF
3AH COS | 4DH PTR
3BH TAN | 4EH Reserved
3CH ASN | 4FH UDG
3DH ACS | 50H NUMBER
3EH ATN | 51H LEN
3FH LOGN | 52H CODE
40H EXP | 53H VAL$
41H ABS | 54H VAL
42H SQN | 55H TRUNC$
43H SOR | 56H CHR$
44H INT | 57H STR$
45H USR | 58H BIN$
46H IN | 59H HEX$
47H PEEK | 5AH USR$
48H DPEEK | 5BH INKEY$ #
49H DVAR | 5CH NOT
4AH SVAR | 5DH NEGATE
4BH BUTTON

SAM Coupe Technical Manual version 5.0 51

Sam Coupe Technical Manual version 3.0 | 52

The calculator has six 5-byte memories for holding temporary results. The following codes store and recall the memories:

C8H STOD0 | Copy the last value to calculator memory 0-5,
C9H STOD1 | then delete it from the FPCS.
CAH STOD2
CBH STOD3
CCH STOD4
CDH STOD5
D0H STO0 | As above, but do not delete the last value
D1H STOl | after copying it.
D2H STO2
D3H STO3
D4H STO4
D5H STO5
DBH RCL0 | Stack the value in calculator memory 0-5 on.
D9H RCLl | the FPCS
DAH RCL2
DBH RCL3
DCH RCL4
DDH RCL5

The codes below provide a compact method of stacking comanonly used constants on the FPCS:

E0H STKHALF | Stack 0.5
ElH STKZERO | Stack zero
E2H STX1SK | Stack 16384
EGH STKFONE | Stack 5-byte form of 1.
E9H STKONE | Stack integer form of 1.
ECH STKTEN | Stack 10.
FOE STKRALFPI | Stack PI/2

Sam Coupe Technical Manual version 3.0 | 53

TAPE SYSTEM

There are five types of tape files; Basic program, Machine Code, Numeric array, String array and SCREEN$. File saving occurs at a selectable speed which can be set to match Spectrum tape speeds. The header format is different from the Spectrum's and will not be recognised by a Spectrum as a header. The data block format is the same as on the Spectrum, but it may contain up to 512K. SCREEN$ files normally contain the palette settings (40 bytes) and line interrupt table, (1 to 509 bytes), so even a screen that switches the palette part-way down a screen can be reloaded. The screen mode is set appropriately before loading of the data block begins.

Files are loaded at the correct speed automatically. Spectrum CODE file headers are converted into the SAM equivalent and then used to load the data block. Spectrum CODE files can be loaded into the Coupe as either CODE or SCREEN$ files by specifying this after the LOAD command. (The Coupe distinguishes SCREEN$ files from CODE files because they have to be loaded to screen memory, which can be anywhere in the memory map). Coupe CODE files can be forced to load as SCREEN$ files, and vice versa, simply by using LOAD "name" CODE or SCREEN$. CODE files can have an execution address.

Altering the system variable TPROMPTS (SVAR 50) can turn off the prompt before SAVE, and/or the printing of file as names they are read from tape.

- FILE HEADER FORMAT -

Tape, disk and Net use a common header format as far as the Basic interpreter is concerned. (The DOS holds information in a slightly different format for its own use, but uses information from, and passes information to, the standard header buffers). SAVE uses a single buffer, HDR (Header-requested) at 4B00H where the details of the file to be saved are built up before the header and then the data are saved. LOAD also uses this buffer, plus an extra one, HDL (Header-loaded) at 4850H which is used to load file headers for comparison with HDR (On the Coupe a "tape header reader" program just consists of a program to PEEK the HDL buffer). (NB There is an extra file type in SAMDOS - .SNP).

HEADER BUFFER FORMAT (HDR and HDL):

0 | - (1) | Type. 5 is a Spectrum 48K snapshot, 16 is a Basic program, 17 is a Numeric array, 18 is a String or string array, 19 is a CODE file, and 20 is a SCREEN$ file.
1-10 | - (10) File name, padded with spaces.
11-14 | - (4) | Allows longer file name if DEVICE is not T, for example 'D2:filenamexx'. SAMDOS will strip off any device identifier, so the maximum length of a filename is still ten characters.

Sam Coupe Technical Manual version 3.0 | 54
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

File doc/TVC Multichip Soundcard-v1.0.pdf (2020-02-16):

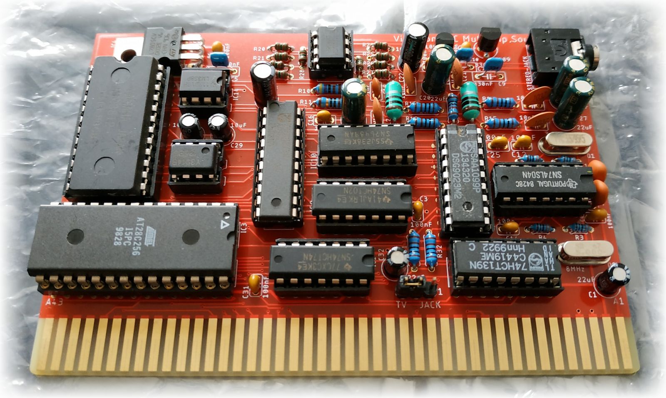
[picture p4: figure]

# TVC Multichip Soundcard

### 2019.11.13. (Peti fiam szülinapja)

─

# Vass Sándor

Egy TVC rajongó

## Áttekintés

Ez a dokumentum a Videoton TV Computer 8 bites személyi számítógéphez készült ‘TVC Multichip Soundcard’ (v1.3) kártya leírását tartalmazza.

2019.11.16 - v1.0

# Tartalomjegyzék

Célok | 2
Specifikáció | 2
Hardware | 2
SN76489 | 3
SAA1099 | 3
YM3812 - OPL2 | 4
Memória - ROM | 4
Regiszterek címzése | 5
Alap I/O cím (Base I/O Address) - egy kis TVC hardver sajátosság | 5
Kártya lokalizálása programból | 5
Speciális IO portok | 6
Olvasás | 7
Példa | 7
Hangchipek időzítései | 7
A SN76489 rövid leírása | 8
Hangmagasság | 8
Hangerő | 8
Zaj generátor | 9
Adatformátum | 9
Hangmagasság beállítása | 9
Zaj beállítása | 10
Hangerő beállítása | 10
BASIC példaprogram az SN76489 megszólaltatásához | 11
Köszönetnyilvánítás | 12

## Célok

1. Láss, ne csak nézz!
2. Az igazi Jedi nem próbálkozik, hanem csinálja.

## Specifikáció

A TVC Multichip Soundcard (TVC többchipes hangkártya) egy 2019-ben fejlesztett hangkártya Videoton TV Computer 32k, 64k és 64k+ gépekhez, melyen 3 különböző hangchip található. Ezek:
- SN76489
- SAA1099
- YM3812 (és mellette a YM3014B)

Mindhárom chip külön programozható és CPU-tól függetlenül tud hangot generálni. Sorban haladva egyre fejlettebbek.
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

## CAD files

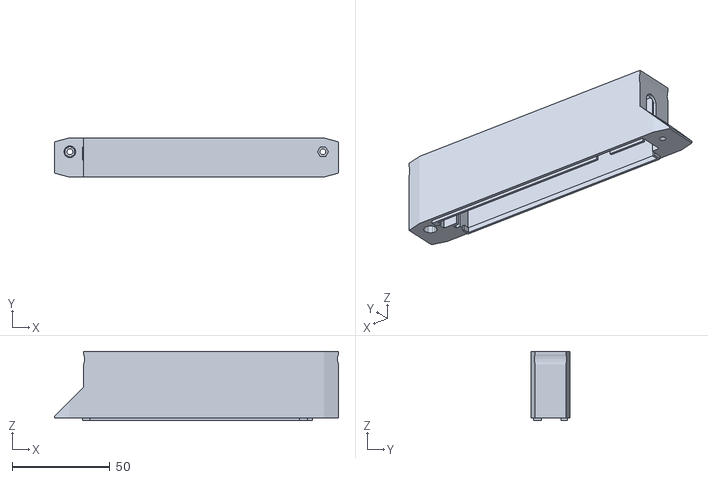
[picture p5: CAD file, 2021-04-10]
box-3d-print/tvcS_Felso.stl
145.5 x 20.0 x 35.5

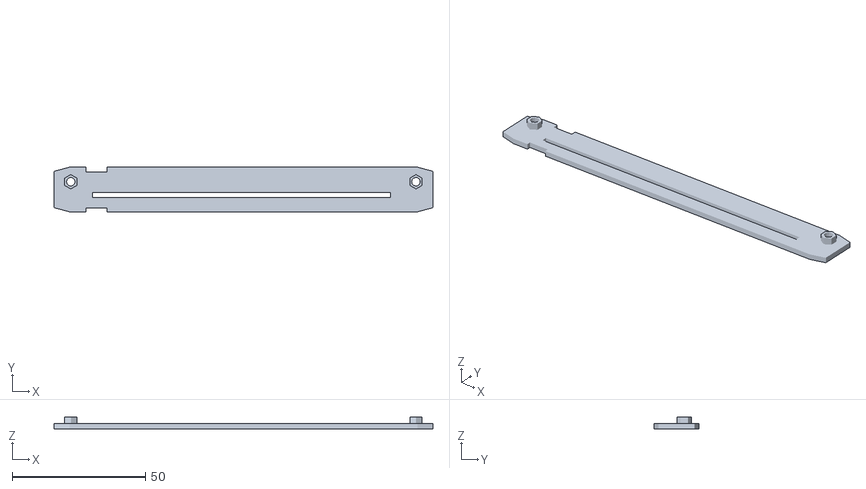
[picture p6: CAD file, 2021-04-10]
box-3d-print/tvcS_Fedlap.stl
142.3 x 16.8 x 4.50

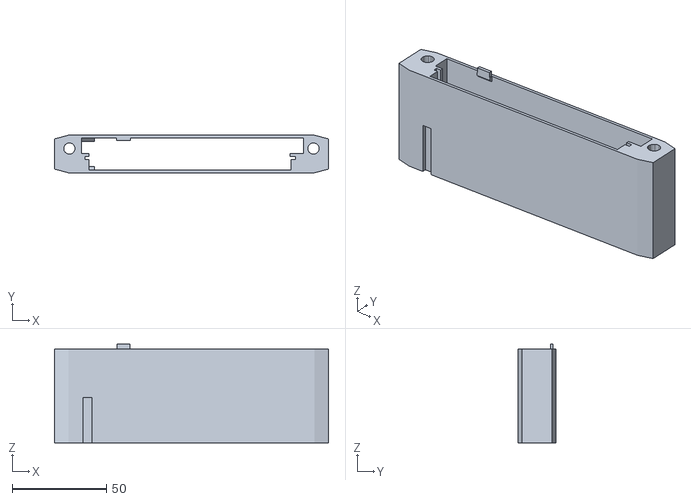
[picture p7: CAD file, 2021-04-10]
box-3d-print/tvcS_Also.stl
145.5 x 20.0 x 52.5

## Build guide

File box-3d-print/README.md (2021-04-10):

# 3D print files

## Magyar
Ebben a könyvtárban a hangkártya 3D nyomtatható dobozának a file-jai találhatóak. Ezek a file-ok Varnyú Ferenc keze munkáját dícsérik, aki GPL v3 -as license -el bocsátotta õket rendelkezésemre.

## English
These files are the 3D print files of the box for the soundcard. These files were created by Ferenc Varnyú and licensed under GPL v3.



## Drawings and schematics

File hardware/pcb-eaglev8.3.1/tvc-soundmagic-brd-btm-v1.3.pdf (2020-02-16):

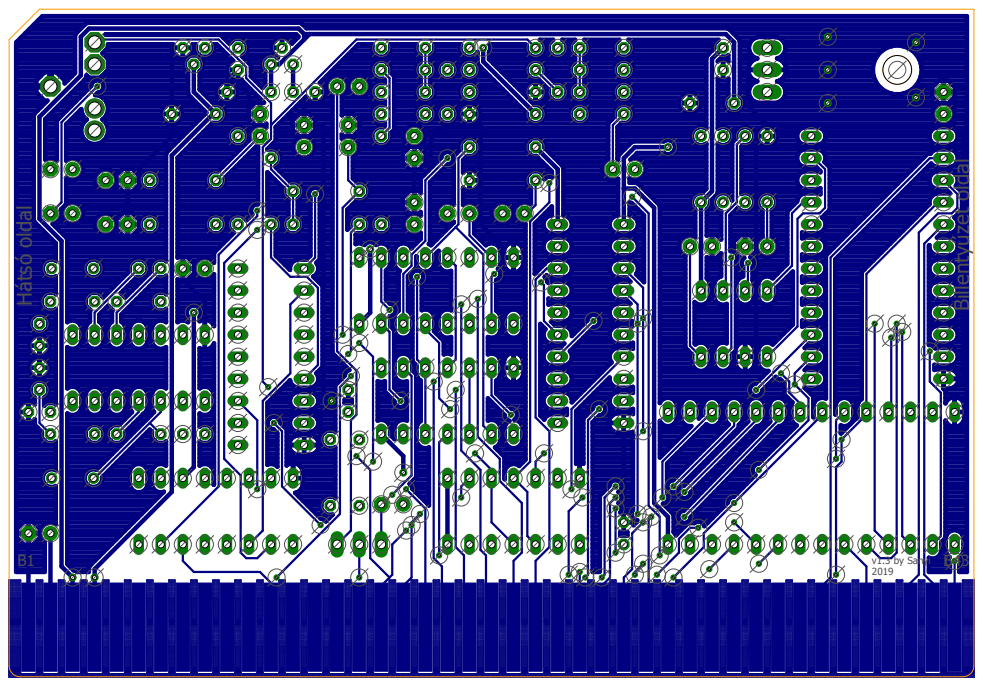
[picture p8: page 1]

Hátsó oldal Billentyűzet oldal v1.3 by Sanyi 2019 B1 B43

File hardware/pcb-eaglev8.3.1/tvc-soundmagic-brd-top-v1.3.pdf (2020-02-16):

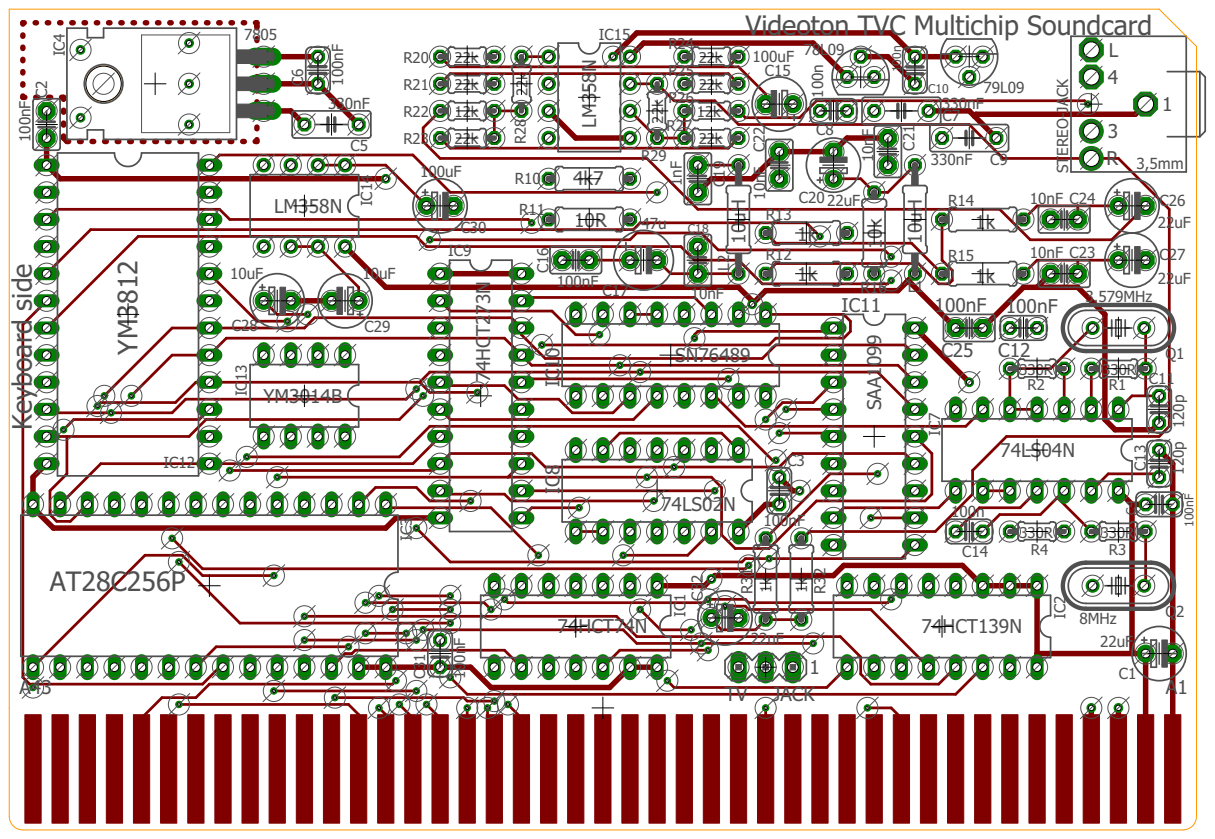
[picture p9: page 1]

Videoton TVC Multichip Soundcard

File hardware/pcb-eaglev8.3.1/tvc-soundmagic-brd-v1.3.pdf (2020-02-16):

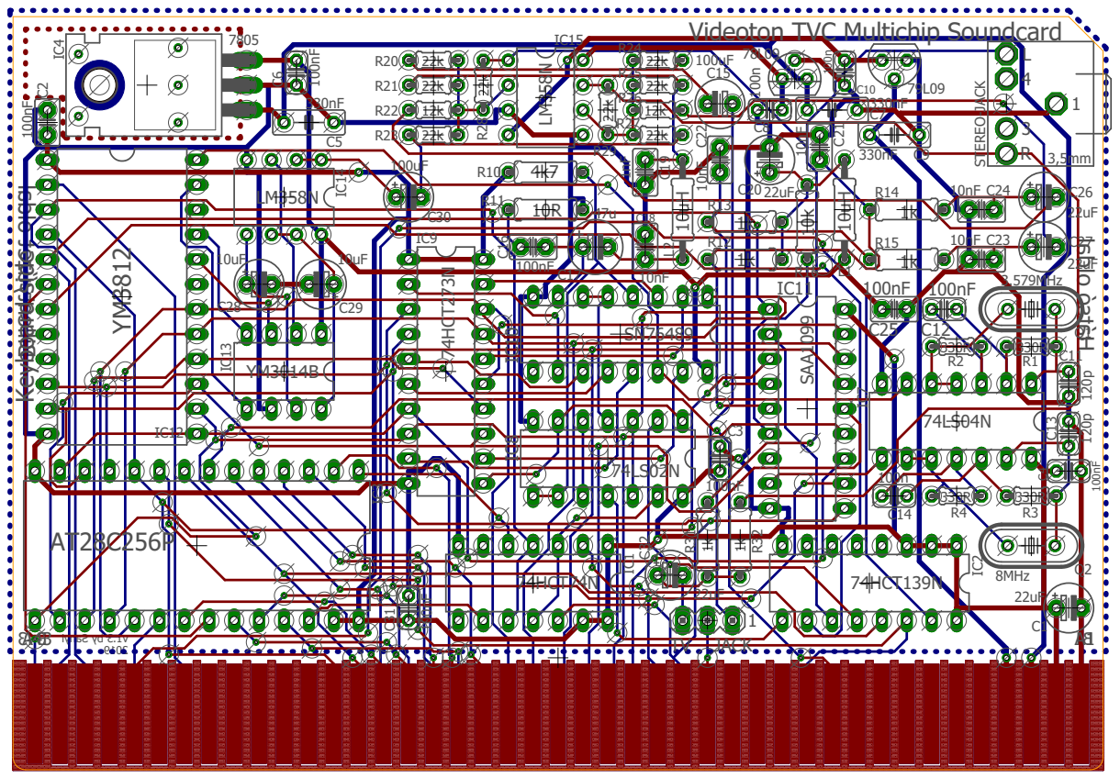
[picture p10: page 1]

Videoton TVC Multichip Soundcard

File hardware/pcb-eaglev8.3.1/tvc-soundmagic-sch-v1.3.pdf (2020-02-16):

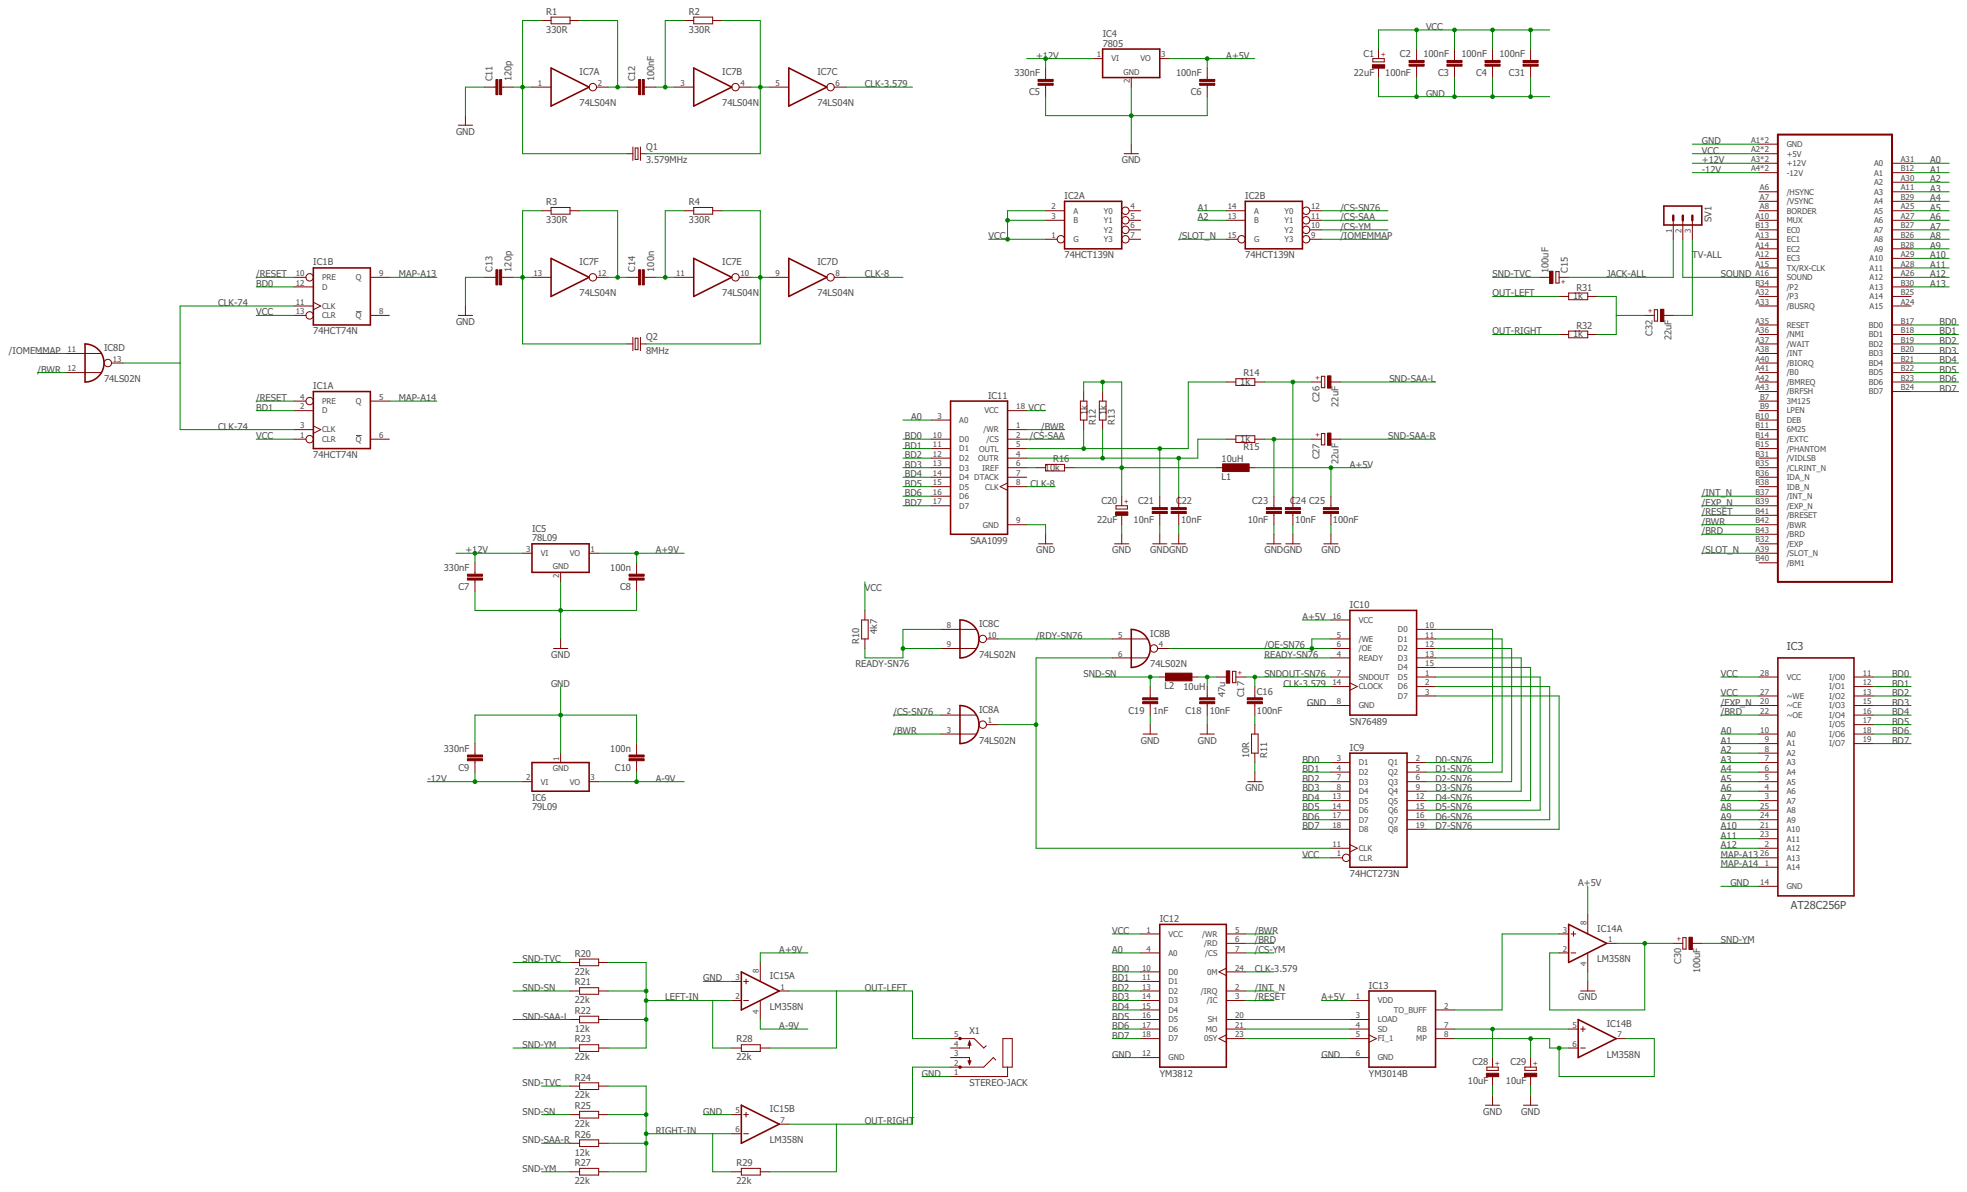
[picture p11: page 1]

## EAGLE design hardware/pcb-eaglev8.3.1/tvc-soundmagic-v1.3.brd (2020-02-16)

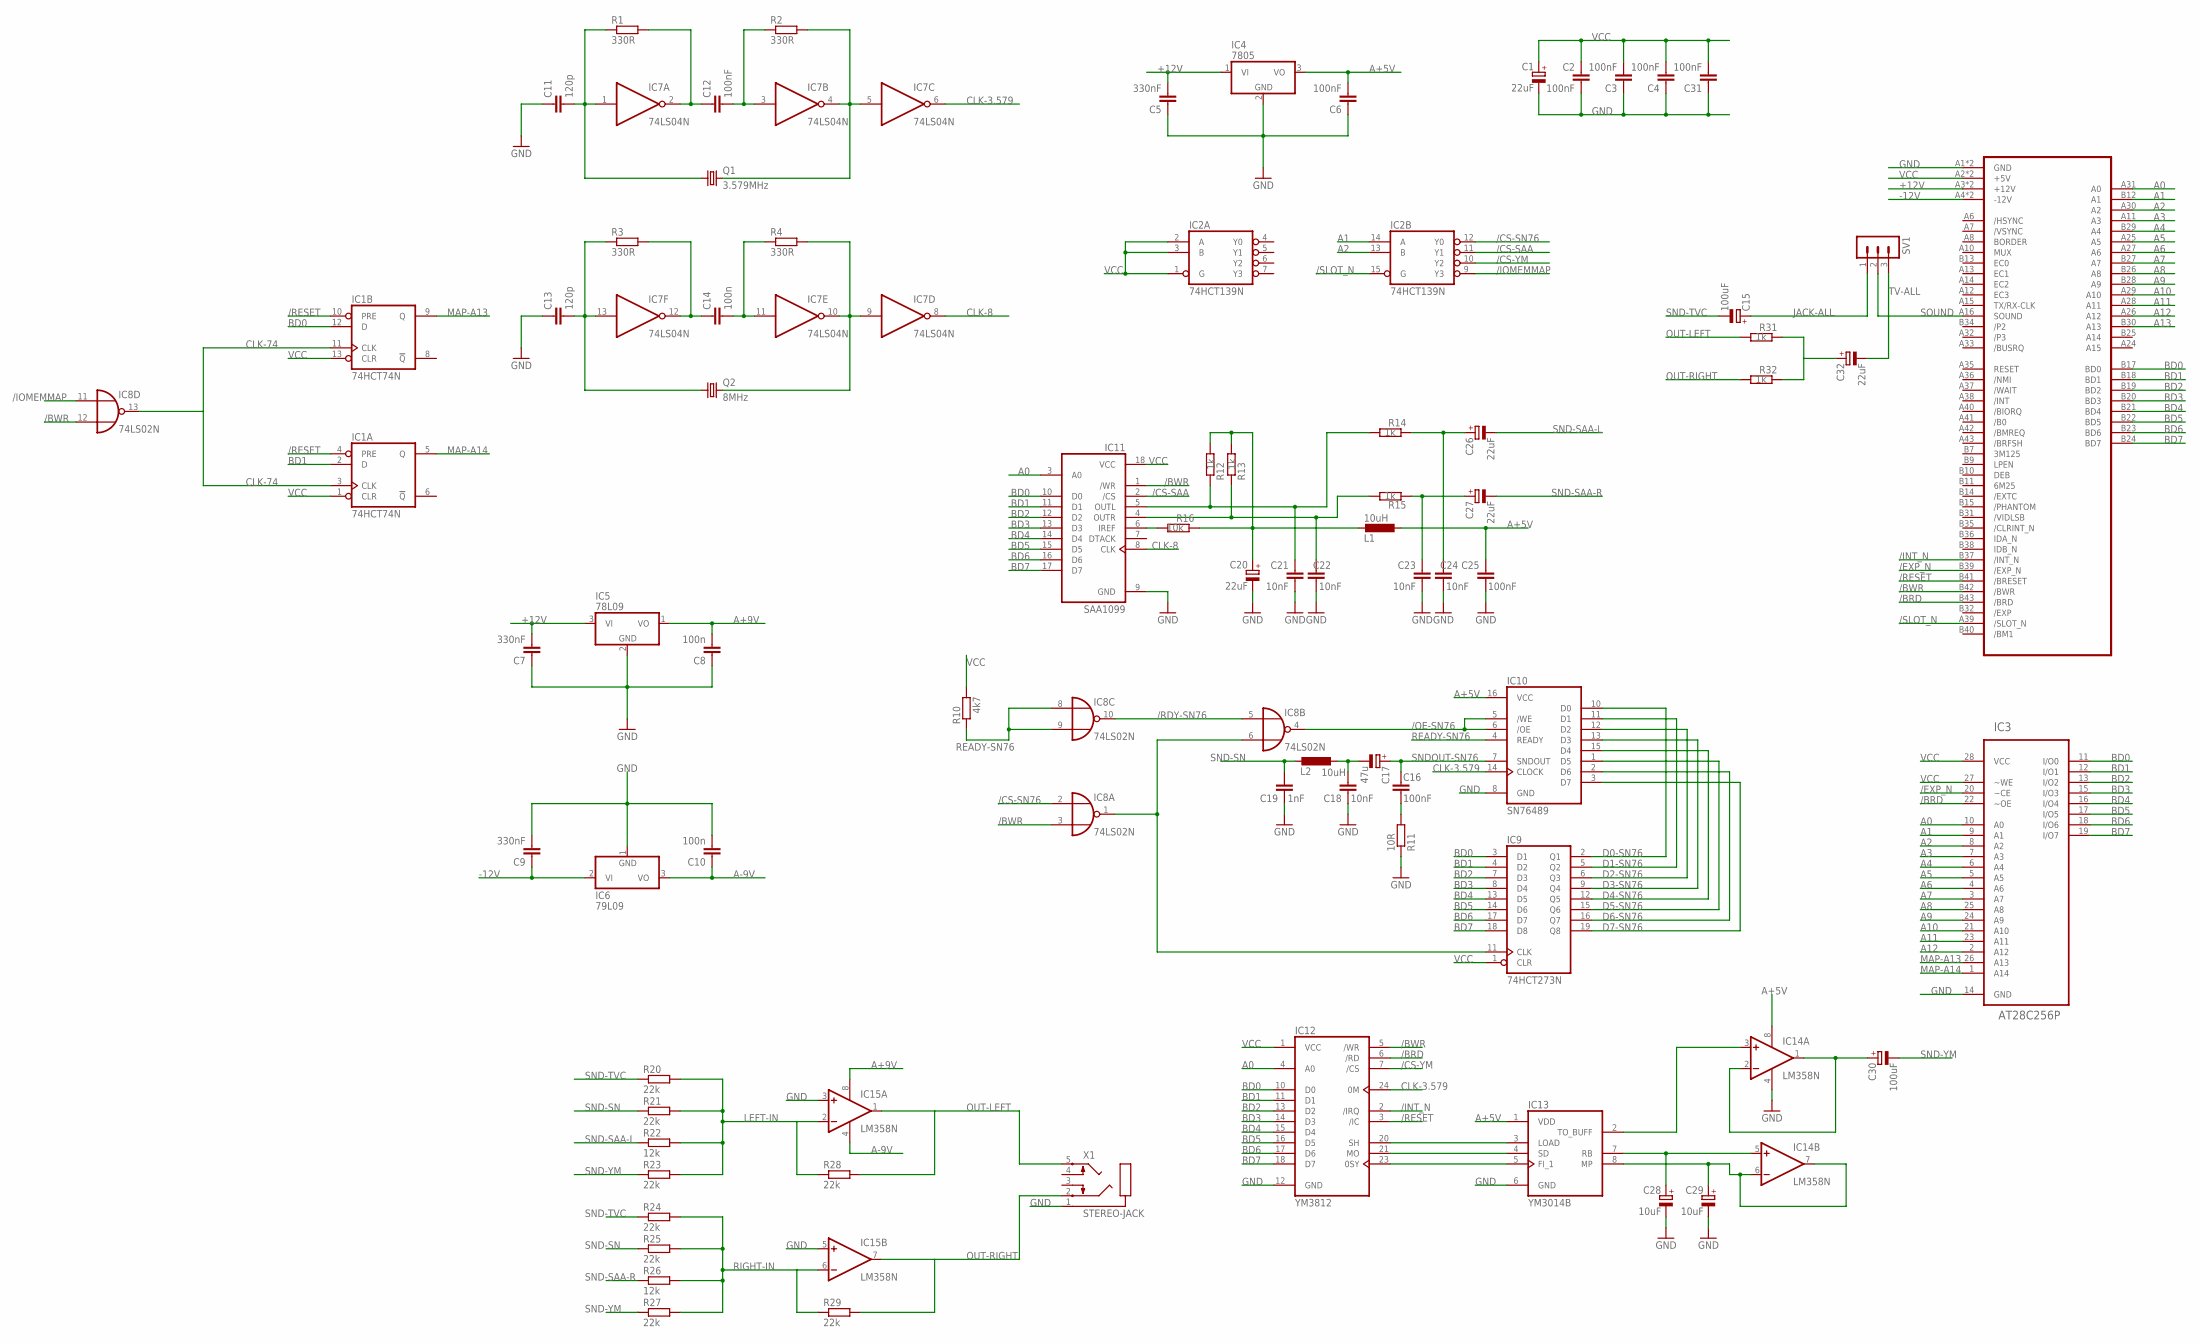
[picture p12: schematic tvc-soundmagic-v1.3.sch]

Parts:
C1, C20, C26, C27, C32: 22uF; E2,5-5
C2, C16, C25: 100nF; C2.5-2
C3, C4, C6, C12, C31: 100nF; C025-024X044
C5, C7, C9: 330nF; C050-025X075
C8, C10, C14: 100n; C025-024X044
C11, C13: 120p; C025-024X044
C15, C30: 100uF; E2,5-5
C17: 47u; E2,5-6
C18, C21, C22, C23, C24: 10nF; C2.5-2
C19: 1nF; C2.5-2
C28, C29: 10uF; E2,5-5
IC1: 74HCT74N; DIL14
IC2: 74HCT139N; DIL16
IC3: AT28C256P; DIL28-6
IC4: 7805; TO220H
IC5: 78L09; TO92
IC6: 79L09; TO92
IC7: 74LS04N; DIL14
IC8: 74LS02N; DIL14
IC9: 74HCT273N; DIL20
IC10: SN76489; DIL16
IC11: SAA1099; DIL18
IC12: YM3812; DIL24-6
IC13: YM3014B; DIL08
IC14, IC15: LM358N; DIL08
L1, L2: 10uH; 0207/10
Q1: 3.579MHz; HC49/S
Q2: 8MHz; HC49/S
R1, R2, R3, R4: 330R; 0204/5
R10: 4k7; 0207/7
R11: 10R; 0207/7
R12, R13, R14, R15, R31, R32: 1k; 0207/7
R16: 10k; 0207/7
R20, R21, R23, R24, R25, R27, R28, R29: 22k; 0204/5
R22, R26: 12k; 0204/5
SV1: MA03-1
U$3: TVC-EXP-HBA-COMMON; TVC-EXP-EDGE
X1: STEREO-JACK; ST-JACK-100

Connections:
+12V: C5.2, C7.2, IC4.1 (VI), IC5.3 (VI), U$3.A3 (+12V), U$3.B3 (+12V)
-12V: C9.1, IC6.2 (VI), U$3.A4 (-12V), U$3.B4 (-12V)
/BRD: IC3.22 (~OE), IC12.6 (/RD), U$3.B43 (/BRD)
/BWR: IC8.3 (I1), IC8.12 (I1), IC11.1 (/WR), IC12.5 (/WR), U$3.B42 (/BWR)
/CS-SAA: IC2.11 (Y1), IC11.2 (/CS)
/CS-SN76: IC2.12 (Y0), IC8.2 (I0)
/CS-YM: IC2.10 (Y2), IC12.7 (/CS)
/EXP_N: IC3.20 (~CE), U$3.B39 (/EXP_N)
/INT_N: IC12.2 (/IRQ), U$3.B37 (/INT_N)
/IOMEMMAP: IC2.9 (Y3), IC8.11 (I0)
/OE-SN76: IC8.4 (O), IC10.5 (/WE), IC10.6 (/OE)
/RDY-SN76: IC8.5 (I0), IC8.10 (O)
/RESET: IC1.4 (PRE), IC1.10 (PRE), IC12.3 (/IC), U$3.B41 (/BRESET)
/SLOT_N: IC2.15 (G), U$3.A39 (/SLOT_N)
A0: IC3.10 (A0), IC11.3 (A0), IC12.4 (A0), U$3.A31 (A0)
A1: IC2.14 (A), IC3.9 (A1), U$3.B12 (A1)
A2: IC2.13 (B), IC3.8 (A2), U$3.A30 (A2)
A3: IC3.7 (A3), U$3.A11 (A3)
A4: IC3.6 (A4), U$3.B29 (A4)
A5: IC3.5 (A5), U$3.A25 (A5)
A6: IC3.4 (A6), U$3.A27 (A6)
A7: IC3.3 (A7), U$3.B27 (A7)
A8: IC3.25 (A8), U$3.B26 (A8)
A9: IC3.24 (A9), U$3.B28 (A9)
A10: IC3.21 (A10), U$3.A29 (A10)
A11: IC3.23 (A11), U$3.A28 (A11)
A12: IC3.2 (A12), U$3.A26 (A12)
A13: U$3.B30 (A13)
A+5V: C6.2, C25.1, IC4.3 (VO), IC10.16 (VCC), IC13.1 (VDD), IC14.8 (V+), L1.1
A+9V: C8.2, IC5.1 (VO), IC15.8 (V+)
A-9V: C10.1, IC6.3 (VO), IC15.4 (V-)
BD0: IC1.12 (D), IC3.11 (I/O0), IC9.3 (D1), IC11.10 (D0), IC12.10 (D0), U$3.B17 (BD0)
BD1: IC1.2 (D), IC3.12 (I/O1), IC9.4 (D2), IC11.11 (D1), IC12.11 (D1), U$3.B18 (BD1)
BD2: IC3.13 (I/O2), IC9.7 (D3), IC11.12 (D2), IC12.13 (D2), U$3.B19 (BD2)
BD3: IC3.15 (I/O3), IC9.8 (D4), IC11.13 (D3), IC12.14 (D3), U$3.B20 (BD3)
BD4: IC3.16 (I/O4), IC9.13 (D5), IC11.14 (D4), IC12.15 (D4), U$3.B21 (BD4)
BD5: IC3.17 (I/O5), IC9.14 (D6), IC11.15 (D5), IC12.16 (D5), U$3.B22 (BD5)
BD6: IC3.18 (I/O6), IC9.17 (D7), IC11.16 (D6), IC12.17 (D6), U$3.B23 (BD6)
BD7: IC3.19 (I/O7), IC9.18 (D8), IC11.17 (D7), IC12.18 (D7), U$3.B24 (BD7)
CLK-3.579: IC7.6 (O), IC10.14 (CLOCK), IC12.24 (0M)
CLK-8: IC7.8 (O), IC11.8 (CLK)
CLK-74: IC1.3 (CLK), IC1.11 (CLK), IC8.13 (O)
D0-SN76: IC9.2 (Q1), IC10.10 (D0)
D1-SN76: IC9.5 (Q2), IC10.11 (D1)
D2-SN76: IC9.6 (Q3), IC10.12 (D2)
D3-SN76: IC9.9 (Q4), IC10.13 (D3)
D4-SN76: IC9.12 (Q5), IC10.15 (D4)
D5-SN76: IC9.15 (Q6), IC10.1 (D5)
D6-SN76: IC9.16 (Q7), IC10.2 (D6)
D7-SN76: IC9.19 (Q8), IC10.3 (D7)
GND: C1.-, C2.2, C3.1, C4.1, C5.1, C6.1, C7.1, C8.1, C9.2, C10.2, C11.1, C13.1, C18.2, C19.2, C20.-, C21.2, C22.2, C23.2, C24.2, C25.2, C28.-, C29.-, C31.1, IC1.7 (GND), IC2.8 (GND), IC3.14 (GND), IC4.2 (GND), IC5.2 (GND), IC6.1 (GND), IC7.7 (GND), IC8.7 (GND), IC9.10 (GND), IC10.8 (GND), IC11.9 (GND), IC12.12 (GND), IC13.6 (GND), IC14.4 (V-), IC15.3 (+IN), IC15.5 (+IN), R11.1, U$3.A1 (GND), U$3.B1 (GND), X1.1 (SHIELD)
JACK-ALL: C15.+, SV1.1
LEFT-IN: IC15.2 (-IN), R20.2, R21.2, R22.2, R23.2, R28.1
MAP-A13: IC1.9 (Q), IC3.26 (A13)
MAP-A14: IC1.5 (Q), IC3.1 (A14)
unnamed: C21.1, IC11.5 (OUTL), R12.1, R14.2
unnamed: C22.1, IC11.4 (OUTR), R13.1, R15.2
unnamed: C20.+, L1.2, R12.2, R13.2, R16.1
unnamed: IC11.6 (IREF), R16.2
unnamed: C32.+, R31.1, R32.1
unnamed: C11.2, IC7.1 (I), Q1.1, R1.1
unnamed: C12.1, IC7.2 (O), R1.2
unnamed: C12.2, IC7.3 (I), R2.1
unnamed: IC8.1 (O), IC8.6 (I1), IC9.11 (CLK)
unnamed: C23.1, C27.+, R15.1
unnamed: C24.1, C26.+, R14.1
unnamed: C16.2, R11.2
unnamed: IC12.20 (SH), IC13.3 (LOAD)
unnamed: IC12.21 (MO), IC13.4 (SD)
unnamed: IC7.4 (O), IC7.5 (I), Q1.2, R2.2
unnamed: C13.2, IC7.13 (I), Q2.1, R3.1
unnamed: IC12.23 (0SY), IC13.5 (FI_1)
unnamed: C28.+, IC13.7 (RB), IC14.5 (+IN)
unnamed: C14.1, IC7.12 (O), R3.2
unnamed: C14.2, IC7.11 (I), R4.1
unnamed: C17.-, C18.1, L2.1
unnamed: IC7.9 (I), IC7.10 (O), Q2.2, R4.2
unnamed: C30.+, IC14.1 (OUT), IC14.2 (-IN)
unnamed: IC13.2 (TO_BUFF), IC14.3 (+IN)
unnamed: C29.+, IC13.8 (MP), IC14.6 (-IN), IC14.7 (OUT)
OUT-LEFT: IC15.1 (OUT), R28.2, R31.2, X1.5 (LEFT)
OUT-RIGHT: IC15.7 (OUT), R29.2, R32.2, X1.2 (RIGHT)
READY-SN76: IC8.8 (I0), IC8.9 (I1), IC10.4 (READY), R10.1
RIGHT-IN: IC15.6 (-IN), R24.2, R25.2, R26.2, R27.2, R29.1
SND-SAA-L: C26.-, R22.1
SND-SAA-R: C27.-, R26.1
SND-SN: C19.1, L2.2, R21.1, R25.1
SND-TVC: C15.-, R20.1, R24.1
SND-YM: C30.-, R23.1, R27.1
SNDOUT-SN76: C16.1, C17.+, IC10.7 (SNDOUT)
SOUND: SV1.2, U$3.A16 (SOUND)
TV-ALL: C32.-, SV1.3
VCC: C1.+, C2.1, C3.2, C4.2, C31.2, IC1.1 (CLR), IC1.13 (CLR), IC1.14 (VCC), IC2.1 (G), IC2.2 (A), IC2.3 (B), IC2.16 (VCC), IC3.27 (~WE), IC3.28 (VCC), IC7.14 (VCC), IC8.14 (VCC), IC9.1 (CLR), IC9.20 (VCC), IC11.18 (VCC), IC12.1 (VCC), R10.2, U$3.A2 (+5V), U$3.B2 (+5V)

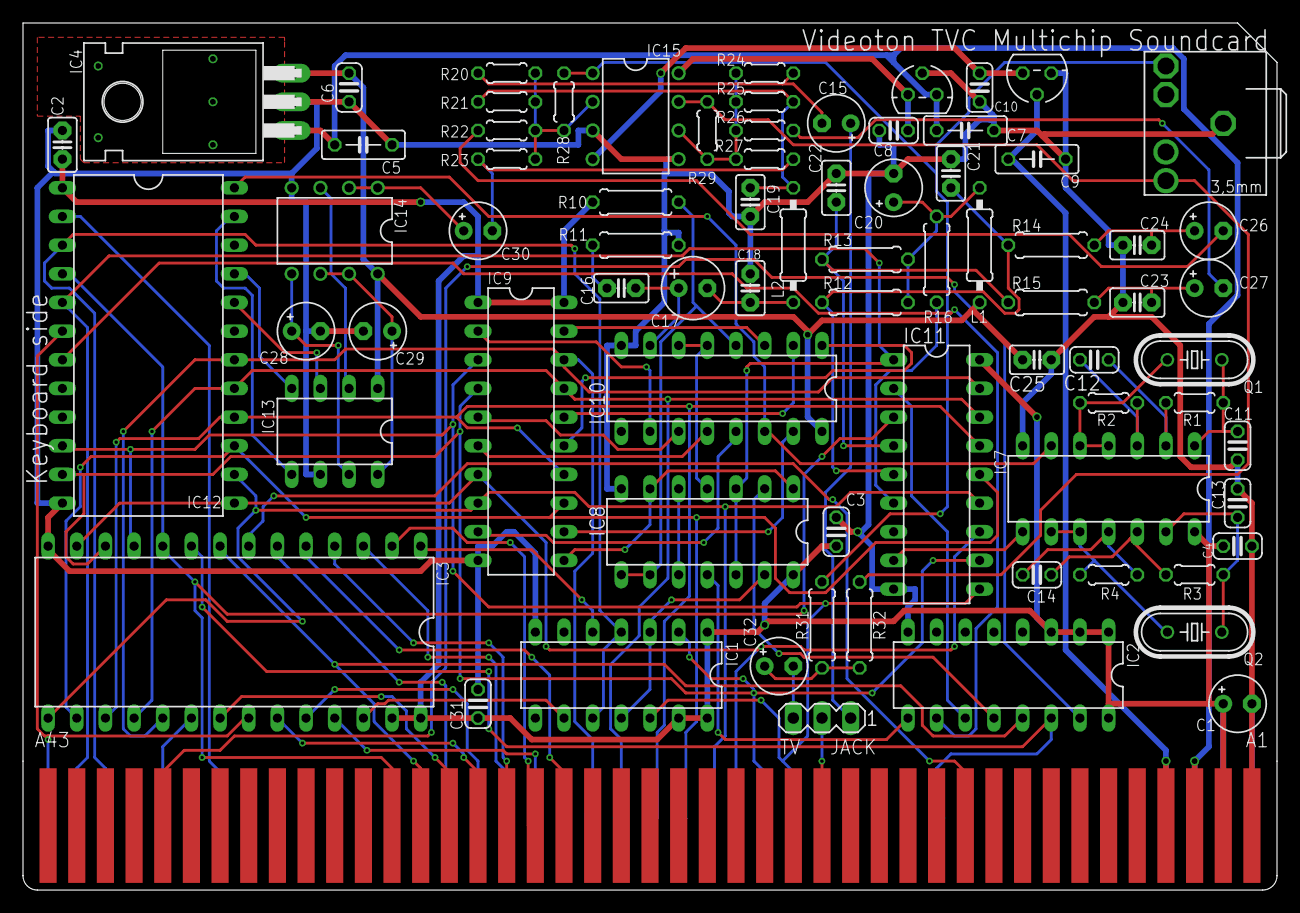
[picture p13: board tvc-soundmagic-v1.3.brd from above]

Board: 2 copper layers, 111.1 x 76.8 mm, 77 parts (0 on the bottom side), 92 nets.

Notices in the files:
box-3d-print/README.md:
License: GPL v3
